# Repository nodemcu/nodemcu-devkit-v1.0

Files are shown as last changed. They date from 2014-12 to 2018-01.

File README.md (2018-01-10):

NodeMCU DEVKIT V1.0
==============

A development kit for NodeMCU firmware.

It will make NodeMCU more easy. With a micro USB cable, you can connect NodeMCU devkit to your laptop and flash it without any trouble, just like Arduino.

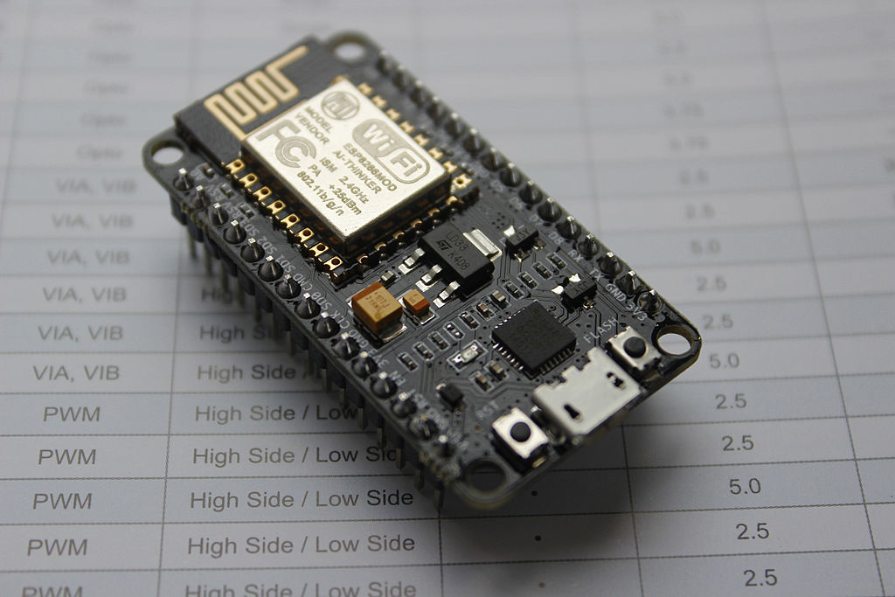
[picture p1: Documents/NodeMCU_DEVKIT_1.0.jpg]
DEVKIT


It is an open hardware, with ESP-12-E core [32Mbits(4MBytes) flash version].

## How to flash
- - - - - -
UPDATE
New nodemcu-flasher is released.
Bug fixed. please use latest software and re-flash.
Enjoy.
https://github.com/nodemcu/nodemcu-flasher
- - - - - -
If always have problem, please use latest flash download tool from espressif.
http://bbs.espressif.com/viewtopic.php?f=5&t=433
Please use DIO mode and 32M flash size option, and flash latest firmware to 0x00000.
Before flashing firmware, please hold FLASH button, and press RST button once.
When our firmware download tool released, it will flash firmware automatically and needn't press any button.

## Pin map

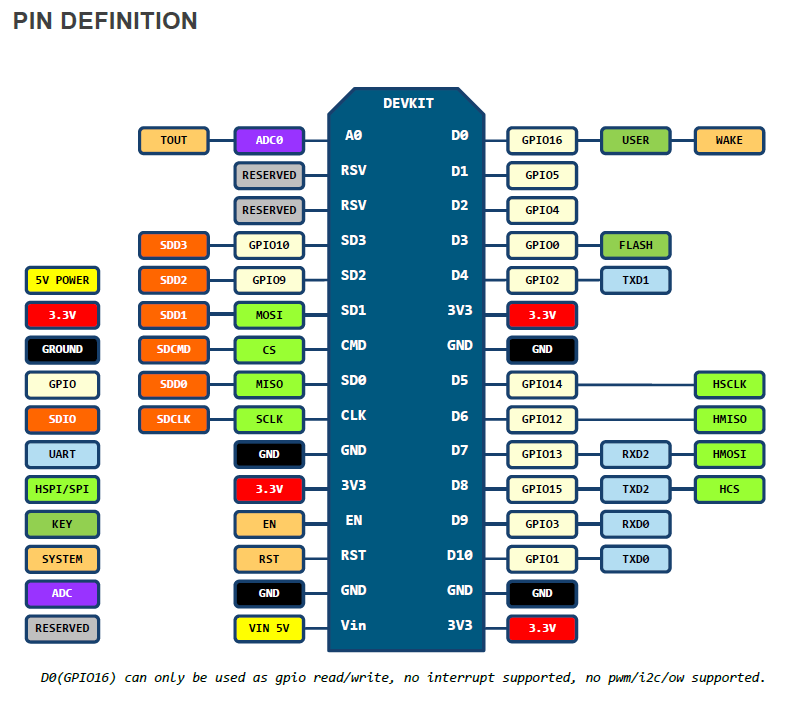
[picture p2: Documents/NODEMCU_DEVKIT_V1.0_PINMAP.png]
PIN MAP


It is designed by Altium Designer, and fully open–source. Now everyone can make their own NODEMCU.

## Designator & Parameter

|Designator|Parameter|
|-|-|
|C1,C4,C6 |100nF (104) ±10% 16V|
|C2 |100uF(107) ±10% 6.3V Case B 3528|
|C3,C5,C8 |10uF(106) ±20% 10V |
|C7|10uF(106) ±10% 25V|
|D1|SOD-123 40V,1A,VF=0.45V@1A|
|LED1|1.6x0.8x0.6 Iv= 35~65mcd @IF=5mA ESD:1000V |
|R1,R2,R3,R4,R5,R7,R8|12KΩ (1202) ±1% 0.0625W [50V TYP] [100V MAX] T.C.R ±100|
|R6,R9,R11,R12|470Ω (4700) ±1% 0.0625W [50V TYP] [100V MAX] T.C.R ±100|
|R10(Do not install)|0Ω (0R00) ±1% 0.0625W [50V TYP] [100V MAX] T.C.R ±100|
|R13|220kΩ (2203) ±1% 0.0625W [50V TYP] [100V MAX] T.C.R ±100|
|R14|100kΩ (1003) ±1% 0.0625W [50V TYP] [100V MAX] T.C.R ±100|

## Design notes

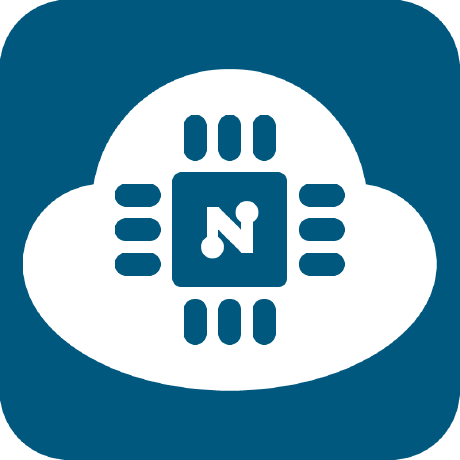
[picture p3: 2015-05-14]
Documents/NodeMCU.png

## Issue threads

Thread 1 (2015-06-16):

File writes fail all the time

rjpcomputing, 2015-06-16:
Hi,

I can not save files to the file system on my board. I have tried the last 4 firmware releases and it doesn't change the problem. It seems to be related to the  amica boards. I have the revision before this and it works 100% of the time.

```lua
file.open("script1.lua","w+")
file.writeline([[print( "Hello World" )]])
file.close()
```
**OUTPUT**:
```
stdin:1: open a file first
```

I am opening the file on the first line.

Please help

vowstar, 2015-06-17:
Hello, you may use old flashtool.
Options:
1. Please use latest esptool.py and with DIO option to flash firmware.
https://github.com/themadinventor/esptool
2. Please use latest NodeMCU flasher with default option (must click 'restore to default' in advanced tab)
https://github.com/nodemcu/nodemcu-flasher
3. Please use latest Espressif's flash tool(without auto download support)
If always have problem, please use latest flash download tool from espressif. http://bbs.espressif.com/viewtopic.php?f=5&t=433 Please use DIO mode and 32M flash size option, and flash latest firmware to 0x00000. Before flashing firmware, please hold FLASH button, and press RST button once. When our firmware download tool released, it will flash firmware automatically and needn't press any button.

rjpcomputing, 2015-06-17:
Hi,

I have been using `esptool.py` downloaded from the master branch (e96336f6561109e67afe03c0695d1e5b0de15da6) and it did not work.

Here is the commandline I am using:
```
./esptool.py --port /dev/ttyUSB0 write_flash 0x00000 <firmware> -fs 32m -fm dio -ff 40m
```
I am using the Amica black board on Linux.

Air000, 2015-06-26:
I have the same problem with @rjpcomputing , also using the Amica black board.
I tried all the methods. Only the tool on http://bbs.espressif.com/viewtopic.php?f=5&t=433 work fine.
But I need esptool.py on Linux

leonciokof, 2015-07-13:
@Air000 how to use esptool from http://bbs.espressif.com/viewtopic.php?f=5&t=433 ?

Air000, 2015-07-17:
@leonciokof
my esptool.py is download from https://github.com/themadinventor/esptool/blob/master/esptool.py.
and I test the esptool from  http://bbs.espressif.com/viewtopic.php?f=5&t=433, also output nothing.

rjpcomputing, 2015-07-23:
@vowstar Why is this closed? The bug is not fixed. Should this be reported on a different tracker?

I don't think that Wine + flash_download_tool.exe is a good enough solution when a feature of NodeMCU is cross-platform.

Thoughts?

rjpcomputing, 2015-07-23:
I think esptool might have got a fix. I have yet to test it, but the commit looks like it should work.
https://github.com/themadinventor/esptool/commit/043f9287c6f7d8a8c2579395f790629f3d85683c

Has anyone tried esptool after July 8th?

rjpcomputing, 2015-08-03:
Just to let other know I was able to use the latest esptool (>July 8th) to flash the board.

Closed 2015-07-23.

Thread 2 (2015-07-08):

CP2102 OSX drivers?

MacDada, 2015-07-08:
Where do I find **working** drivers for OSX 10.10 (Yosemite)?

1. I have OSX `10.10.3` on `MBP11,2`
2. I downloaded OSX drivers from [the vendor website](https://www.silabs.com/products/mcu/Pages/USBtoUARTBridgeVCPDrivers.aspx) ([direct zip download](https://www.silabs.com/Support%20Documents/Software/Mac_OSX_VCP_Driver.zip))
3. Unpacked the ZIP, mounted DMG file, installed using the PKG installer.
4. Restarted computer
5. I connected NodeMcu devkit v1.0 through USB 3.0 port

There is a file/folder `/Library/Extensions/SiLabsUSBDriver.kext`, but no serial port available for the device.

```
$ ls -lah /dev/cu*
crw-rw-rw-  1 root  wheel   18,   1 Jul  8 13:32 /dev/cu.Bluetooth-Incoming-Port
crw-rw-rw-  1 root  wheel   18,   3 Jul  8 13:32 /dev/cu.Bluetooth-Modem
crw-rw-rw-  1 root  wheel   18,   5 Jul  8 13:32 /dev/cu.DadaFon4-WirelessiAP

$ ls -lah /dev/tty.*
crw-rw-rw-  1 root  wheel   18,   0 Jul  8 13:32 /dev/tty.Bluetooth-Incoming-Port
crw-rw-rw-  1 root  wheel   18,   2 Jul  8 13:32 /dev/tty.Bluetooth-Modem
crw-rw-rw-  1 root  wheel   18,   4 Jul  8 13:32 /dev/tty.DadaFon4-WirelessiAP
```

No success with ESPlorer and Arduino IDE.

----
__EDIT 1__

Apparently it works for some people (?), but not for me: http://blog.squix.ch/2015/05/esp8266-flashing-nodemcu-v10-on-mac-os.html

----
__EDIT 2:__

It looks like the kext isn't loaded?

```
$ kextstat
Index Refs Address            Size       Wired      Name (Version) <Linked Against>
    1   92 0xffffff7f80a3e000 0x8c50     0x8c50     com.apple.kpi.bsd (14.3.0)
    2    7 0xffffff7f80f9c000 0x28c0     0x28c0     com.apple.kpi.dsep (14.3.0)
    3  118 0xffffff7f80a03000 0x20500    0x20500    com.apple.kpi.iokit (14.3.0)
    4  125 0xffffff7f80a24000 0xbf50     0xbf50     com.apple.kpi.libkern (14.3.0)
    5  108 0xffffff7f80a00000 0x2d50     0x2d50     com.apple.kpi.mach (14.3.0)
    6   53 0xffffff7f80a30000 0x8590     0x8590     com.apple.kpi.private (14.3.0)
    7   71 0xffffff7f80a39000 0x4900     0x4900     com.apple.kpi.unsupported (14.3.0)
    8    4 0xffffff7f80da3000 0x9c000    0x9c000    com.apple.kec.corecrypto (1.0) <7 6 5 4 3 1>
    9    0 0xffffff7f80ea4000 0xc000     0xc000     com.apple.kec.pthread (1) <7 6 5 4 1>
   10    1 0xffffff7f80fd5000 0x9000     0x9000     com.apple.kec.Libm (1) <4>
   11   23 0xffffff7f813b7000 0x9000     0x9000     com.apple.iokit.IOACPIFamily (1.4) <7 6 4 3>
   12   31 0xffffff7f80b24000 0x2f000    0x2f000    com.apple.iokit.IOPCIFamily (2.9) <7 6 5 4 3>
   13    2 0xffffff7f82956000 0x5f000    0x5f000    com.apple.driver.AppleACPIPlatform (3.1) <12 11 7 6 5 4 3 1>
   14    1 0xffffff7f810a5000 0xb000     0xb000     com.apple.driver.AppleFDEKeyStore (28.30) <8 7 6 5 4 3 1>
   15    2 0xffffff7f813b0000 0x7000     0x7000     com.apple.iokit.IOReportFamily (31) <5 4 3>
   16   10 0xffffff7f80a47000 0x26000    0x26000    com.apple.iokit.IOStorageFamily (2.0) <7 6 5 4 3 1>
   17    0 0xffffff7f814a7000 0x19000    0x19000    com.apple.driver.DiskImages (396) <16 7 6 5 4 3 1>
   18    1 0xffffff7f822ce000 0xf000     0xf000     com.apple.driver.AppleCredentialManager (1.0) <7 5 4 3 1>
   19    2 0xffffff7f80fa2000 0xd000     0xd000     com.apple.driver.AppleMobileFileIntegrity (1.0.5) <7 6 5 4 3 2 1>
   20    0 0xffffff7f822dd000 0x23000    0x23000    com.apple.driver.AppleKeyStore (2) <19 18 8 7 6 5 4 3 1>
   21    0 0xffffff7f80f9f000 0x2000     0x2000     com.apple.security.TMSafetyNet (8) <7 6 5 4 2 1>
   22    2 0xffffff7f80faf000 0x5000     0x5000     com.apple.kext.AppleMatch (1.0.0d1) <4 1>
   23    1 0xffffff7f80fb4000 0x17000    0x17000    com.apple.security.sandbox (300.0) <22 19 7 6 5 4 3 2 1>
   24    0 0xffffff7f80fcb000 0x9000     0x9000     com.apple.security.quarantine (3) <23 22 7 6 5 4 2 1>
   25    0 0xffffff7f829cc000 0x8000     0x8000     com.apple.nke.applicationfirewall (161) <7 6 5 4 3 1>
   26    0 0xffffff7f82929000 0x3000     0x3000     com.apple.driver.AppleAPIC (1.7) <4 3>
   27    3 0xffffff7f81358000 0x4000     0x4000     com.apple.iokit.IOSMBusFamily (1.1) <5 4 3>
   28    0 0xffffff7f829bb000 0x7000     0x7000     com.apple.driver.AppleACPIEC (3.1) <27 13 11 5 4 3>
   29    0 0xffffff7f821e9000 0x4000     0x4000     com.apple.driver.AppleSMBIOS (2.1) <7 4 3>
   30    0 0xffffff7f82546000 0x3000     0x3000     com.apple.driver.AppleHPET (1.8) <11 7 5 4 3>
   31    6 0xffffff7f810b0000 0x76000    0x76000    com.apple.iokit.IOHIDFamily (2.0.0) <14 7 6 5 4 3 2 1>
   32    0 0xffffff7f829c5000 0x4000     0x4000     com.apple.driver.AppleACPIButtons (3.1) <31 13 11 7 6 5 4 3 1>
   33    0 0xffffff7f8220a000 0x8000     0x8000     com.apple.driver.AppleRTC (2.0) <11 5 4 3 1>
   34    1 0xffffff7f825bb000 0x5000     0x5000     com.apple.driver.AppleEFIRuntime (2.0) <7 6 5 4 3>
   35    0 0xffffff7f821d1000 0x8000     0x8000     com.apple.driver.AppleSmartBatteryManager (161.0.0) <27 11 5 4 3 1>
   36    1 0xffffff7f825c0000 0xb000     0xb000     com.apple.driver.AppleEFINVRAM (2.0) <34 7 6 5 4 3 1>
   37   16 0xffffff7f8101d000 0x65000    0x65000    com.apple.iokit.IOUSBFamily (720.4.4) <12 7 5 4 3 1>
   38    0 0xffffff7f81158000 0x22000    0x22000    com.apple.driver.AppleUSBXHCI (710.4.11) <37 12 7 5 4 3 1>
   39    5 0xffffff7f80fde000 0x2c000    0x2c000    com.apple.iokit.IONetworkingFamily (3.2) <7 6 5 4 3 1>
   40    1 0xffffff7f816de000 0x7000     0x7000     com.apple.driver.mDNSOffloadUserClient (1.0.1b8) <39 4 3 1>
   41    1 0xffffff7f816e5000 0xab000    0xab000    com.apple.iokit.IO80211Family (730.60) <39 8 7 6 5 4 3 1>
   42    0 0xffffff7f81798000 0x5e6000   0x5e6000   com.apple.driver.AirPort.Brcm4360 (930.37.3) <41 40 39 12 7 6 5 4 3 1>
   43    7 0xffffff7f8123f000 0xde000    0xde000    com.apple.iokit.IOThunderboltFamily (4.2.2) <5 4 3 1>
   44    0 0xffffff7f820f1000 0x1b000    0x1b000    com.apple.driver.AppleThunderboltNHI (3.1.7) <43 12 11 5 4 3 1>
   45    0 0xffffff7f820df000 0x5000     0x5000     com.apple.driver.AppleThunderboltPCIDownAdapter (2.0.2) <43 12 5 4 3 1>
   46    3 0xffffff7f82133000 0xf000     0xf000     com.apple.driver.AppleThunderboltDPAdapterFamily (4.0.6) <43 11 5 4 3 1>
   47    0 0xffffff7f8215d000 0x6000     0x6000     com.apple.driver.AppleThunderboltDPInAdapter (4.0.6) <46 43 5 4 3 1>
   48    3 0xffffff7f81686000 0x16000    0x16000    com.apple.iokit.IOAHCIFamily (2.7.5) <5 4 3 1>
   49    0 0xffffff7f8292e000 0x1b000    0x1b000    com.apple.driver.AppleAHCIPort (3.1.2) <48 12 5 4 3 1>
   50    0 0xffffff7f816ac000 0x9000     0x9000     com.apple.iokit.IOAHCIPassThrough (1.0.3) <48 5 4 3 1>
   51    0 0xffffff7f816b9000 0x18000    0x18000    com.apple.iokit.IOAHCIBlockStorage (2.7.1) <48 16 6 5 4 3 1>
   52    0 0xffffff7f81fb9000 0x3000     0x3000     com.apple.driver.XsanFilter (404) <16 5 4 3 1>
   53    0 0xffffff7f811bd000 0x1c000    0x1c000    com.apple.driver.AppleUSBHub (705.4.2) <37 5 4 3 1>
   54    0 0xffffff7f81ef5000 0xa000     0xa000     com.apple.BootCache (36) <7 6 5 4 3 1>
   55    0 0xffffff7f8284c000 0x2000     0x2000     com.apple.driver.AppleFileSystemDriver (3.0.1) <16 4 3>
   56    0 0xffffff7f82850000 0x5000     0x5000     com.apple.AppleFSCompression.AppleFSCompressionTypeZlib (1.0.0d1) <6 4 3 2 1>
   57    0 0xffffff7f82857000 0x3000     0x3000     com.apple.AppleFSCompression.AppleFSCompressionTypeDataless (1.0.0d1) <7 6 4 3 2 1>
   58    1 0xffffff7f81df7000 0xde000    0xde000    com.apple.driver.CoreStorage (471.20.7) <16 7 6 5 4 3 1>
   59    0 0xffffff7f81edb000 0x16000    0x16000    com.apple.driver.CoreStorageFsck (471.20.7) <58 16 7 6 5 4 3 1>
   60    1 0xffffff7f8114e000 0xa000     0xa000     com.apple.driver.AppleUSBComposite (705.4.9) <37 4 3 1>
   61    0 0xffffff7f811b6000 0x7000     0x7000     com.apple.driver.AppleUSBMergeNub (705.4.0) <60 37 4 3 1>
   62    4 0xffffff7f80ae2000 0x2b000    0x2b000    com.apple.iokit.IOSCSIArchitectureModelFamily (3.7.5) <5 4 3 1>
   63    1 0xffffff7f8108e000 0x11000    0x11000    com.apple.iokit.IOUSBMassStorageClass (3.7.2) <62 37 16 5 4 3 1>
   64    1 0xffffff7f80eb0000 0x18000    0x18000    com.apple.iokit.IOSCSIBlockCommandsDevice (3.7.5) <62 16 5 4 3 1>
   65    0 0xffffff7f821b6000 0x8000     0x8000     com.apple.driver.AppleUSBCardReader (3.5.5) <64 63 62 37 16 5 4 3 1>
   66    0 0xffffff7f8135c000 0x7000     0x7000     com.apple.iokit.SCSITaskUserClient (3.7.5) <62 16 5 4 3 1>
   67    3 0xffffff7f81144000 0xa000     0xa000     com.apple.iokit.IOUSBHIDDriver (705.4.0) <37 31 5 4 3 1>
   68    0 0xffffff7f81ff2000 0x4000     0x4000     com.apple.driver.AppleUSBTCKeyboard (240.2) <67 37 31 7 6 5 4 3 1>
   69    0 0xffffff7f81ff8000 0x2000     0x2000     com.apple.driver.AppleUSBTCKeyEventDriver (240.2) <31 5 4 3>
   70    0 0xffffff7f82001000 0x13000    0x13000    com.apple.driver.AppleUSBMultitouch (245.2) <67 37 31 6 5 4 3 1>
   71    0 0xffffff7f81ffc000 0x3000     0x3000     com.apple.driver.AppleUSBTCButtons (240.2) <67 37 31 7 6 5 4 3 1>
   72   16 0xffffff7f81450000 0x3b000    0x3b000    com.apple.iokit.IOGraphicsFamily (2.4.1) <12 7 5 4 3 1>
   73    1 0xffffff7f8227b000 0xe000     0xe000     com.apple.driver.AppleSMBusController (1.0.13d1) <27 12 11 5 4 3>
   74    0 0xffffff7f8228c000 0xe000     0xe000     com.apple.driver.AppleMCCSControl (1.2.11) <73 72 12 11 7 5 4 3 1>
   75    4 0xffffff7f81497000 0x10000    0x10000    com.apple.iokit.IONDRVSupport (2.4.1) <72 12 7 5 4 3>
   76    6 0xffffff7f813ca000 0x1a000    0x1a000    com.apple.driver.AppleSMC (3.1.9) <11 7 5 4 3 1>
   77    2 0xffffff7f82820000 0x5000     0x5000     com.apple.driver.AppleBacklightExpert (1.1.0) <75 72 12 5 4 3>
   78    0 0xffffff7f82921000 0x5000     0x5000     com.apple.driver.AppleBacklight (170.7.4) <77 76 75 72 12 5 4 3>
   79    2 0xffffff7f8281d000 0x3000     0x3000     com.apple.driver.AppleGraphicsControl (3.10.22) <72 12 11 7 5 4 3 1>
   80    0 0xffffff7f82825000 0x14000    0x14000    com.apple.driver.AppleMuxControl (3.10.22) <79 77 72 12 11 7 6 5 4 3 1>
   81    1 0xffffff7f82142000 0xe000     0xe000     com.apple.driver.AppleThunderboltDPOutAdapter (4.0.6) <46 43 5 4 3 1>
   82    0 0xffffff7f82150000 0xd000     0xd000     com.apple.driver.AppleThunderboltEDMSink (4.0.2) <81 46 43 5 4 3 1>
   83    6 0xffffff7f813c0000 0xa000     0xa000     com.apple.driver.IOPlatformPluginFamily (5.9.1d7) <11 7 6 5 4 3>
   84    1 0xffffff7f813e6000 0x17000    0x17000    com.apple.driver.X86PlatformPlugin (1.0.0) <83 76 37 11 7 6 5 4 3 1>
   85    1 0xffffff7f81406000 0x12000    0x12000    com.apple.driver.IOPlatformPluginLegacy (1.0.0) <83 11 7 6 5 4 3>
   86    0 0xffffff7f8141a000 0x10000    0x10000    com.apple.driver.ACPI_SMC_PlatformPlugin (1.0.0) <85 83 76 12 11 7 6 5 4 3>
   87    1 0xffffff7f8134e000 0x5000     0x5000     com.apple.iokit.IOSlowAdaptiveClockingFamily (1.0.0) <7 6 5 4 3 1>
   88    0 0xffffff7f82300000 0x2000     0x2000     com.apple.driver.AppleIntelSlowAdaptiveClocking (4.0.0) <87 4 3>
   89    2 0xffffff7f8234f000 0x6f000    0x6f000    com.apple.iokit.IOAcceleratorFamily2 (156.14) <72 12 7 6 5 4 3 1>
   90    3 0xffffff7f82456000 0x6000     0x6000     com.apple.AppleGraphicsDeviceControl (3.10.22) <7 6 5 4 3 1>
   91    0 0xffffff7f8245c000 0x4b000    0x4b000    com.apple.driver.AppleIntelFramebufferAzul (10.0.6) <90 89 72 15 12 11 7 6 5 4 3 1>
   92    0 0xffffff7f82860000 0xa8000    0xa8000    com.apple.driver.AppleCameraInterface (5.33.0) <12 7 6 5 4 3 1>
   93    0 0xffffff7f821de000 0x5000     0x5000     com.apple.driver.AppleSMCLMU (2.0.7d0) <76 72 5 4 3>
   94    1 0xffffff7f810a2000 0x3000     0x3000     com.apple.iokit.IOUSBUserClient (705.4.0) <37 7 5 4 3 1>
   95    0 0xffffff7f821e6000 0x3000     0x3000     com.apple.driver.AppleSMBusPCI (1.0.12d1) <12 5 4 3>
   96    2 0xffffff7f81f01000 0x78000    0x78000    com.apple.vecLib.kext (1.2.0) <10 6 5 4 3>
   97    4 0xffffff7f81f79000 0x30000    0x30000    com.apple.iokit.IOAudioFamily (203.3) <96 5 4 3 1>
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

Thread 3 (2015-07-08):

Cannot flash the firmware from a Mac

marcoskirsch, 2015-07-08:
I have OS X Yosemite. SiLabs drivers for the USB-Serial adapter are installed and working. I can communicate to the board via /dev/cu.SLAB_USBtoUART and I can use it in screen, ESPlorer, esptool.py... but strangely not minicom.

However, I haven't been able to flash new firmware successfully.

Can anyone confirm this can be done? I did it on older ESP01 hardware before but I don't rule out me doing something stupid.

* What tool did you use to flash?
* What firmware image?

I posted additional information here: http://www.esp8266.com/viewtopic.php?f=22&t=3903 but nobody has been able to help. Help is appreciated!

abl, 2015-07-08:
Minicom requires some tweaks to work correctly, iirc - it has to be told to ignore certain signals and lines that are being repurposed.

Ok, so you are actually flashing the build and getting to boot mode 3, which is boot from SPI flash. (Esptool, with a supported USB->Serial, is able to reset devices and put them in to boot mode 1, which is what you use for writing to the flash.) Secondary boot mode not being 7 I tend to associate with power supply issues. I've never found a concrete answer as to what it means.

Based on other bug reports, it looks like you might have a defective flash chip or a nonstandard flash chip - or you're flashing bad firmware. Have you tried flashing the stock NodeMCU firmware? Do you have access to a Windows machine to try the official NodeMCU flasher?

marcoskirsch, 2015-07-08:
I doubt but don't completely rule out a defective flash chip because it was functional out of the box. I do have access to Windows PC and will try that next. In order to rule out a bad firmware image, can you link to an image that is known to work on NodeMCU devkit 1.0?

abl, 2015-07-08:
http://www.esp8266.com/viewtopic.php?p=15306 kind of indicates that, based on your error, something weird is going on with your flash chip. It might need a specialized flasher or a different header. This wouldn't have been a problem...until you tried to flash it or write a large amount of data to flash.

The NodeMCU flasher comes with NodeMCU firmware. I'm not sure which version, though.

Official NodeMCU releases are at https://github.com/nodemcu/nodemcu-firmware/releases - I don't have a NodeMCU 1.0 to test on but I'd expect a lot of issues filed if any of these builds were broken.

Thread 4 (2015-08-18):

V1/V2/V3 difference ?

asetyde, 2015-08-18:
Schematics say about v 0,9 .. but many type at now .. v1 v2 v3 ... therefore ? thx

mqu, 2015-10-25:
you could have a look here : http://frightanic.com/iot/comparison-of-esp8266-nodemcu-development-boards/

asetyde, 2015-10-25:
Many Thx ,

I also understand with my hand this difference , it's a good choice model v2 also doit v3.

In particular about power , use reserve pin to give a special port is more safe and practical that use vin/gnd as bridge to give power.

Minimum power is about 500ma , after 6 month of use I say 1000ma is good .
With sensor and rele 1.5k ma or 2k ma because this board is sensible to lower power down , strange error may appear if power is not enough to cpu minimum needed .

But this board , I think , is a big big successful ! This community also too.

Sent from my iPhone

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

vowstar, 2015-11-24:
NodeMCU only released V0.9 and V1.0 board. The next is V1.1, we plan to release it in 2016.
The main difference is USB to UART bridge IC. V0.9 uses ch340G, but have many problems on MAC, so we released V1.0 which uses CP2102 and have a good performance.

odoveiz, 2016-03-25:
Any news on a new version?

asetyde, 2016-03-29:
on closed issue you can find info , use search

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

asetyde, 2016-03-29:
https://github.com/esp8266/Arduino/issues/1481

asetyde, 2016-03-29:
only nodemcu v2 as nodemcu 1.0 is amica / nodemcu compliance
( v3 has usb different chip ch340 and some power difference / v1 is nodemcu 0.9 )

i suggest use nodemcu 1.0 amica ( v2 ) see post how check it

jk2552, 2017-10-05:
hi folks i need Datasheet of Nodemcu ver0.1 kindly anyone help me..

marcelstoer, 2017-12-27:
Sorry to comment on an old and closed issue. My post that was mentioned above has a photo at https://frightanic.com/iot/comparison-of-esp8266-nodemcu-development-boards/#official-vs-unofficial which shows in detail how an "official" 1.0/v2 devkit has to look like.

To my knowledge neither Banggood nor Aliexpress still sells the Amica v2 devkit. Seeed Studio still has them but it's marked as "out of stock". If you [search taobao.com for "NodeMCU cp2102"](https://s.taobao.com/search?q=NodeMCU+cp2102) it turns up quite a few that look genuine.

Closed 2016-03-29.

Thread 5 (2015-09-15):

Unable to connect to dev kit at all

zdrc, 2015-09-15:
Hi, I recently purchased a nodeMCU dev kit off of amazon.

I'm running Mac 10.10, and I have the most recent CP2102 driver. I own a couple of CP2102 breakouts that I can connect to no problem.

I am entirely unable to get any kind of response out of the dev kit using the micro USB port. Nothing shows up under /dev/tty.* and IO Registry Explorer is unable to locate the device in the USB port. I've tried to circumvent the CP2102 chip on the dev kit using one of my breakouts (connecting txd and rxd) and I seem to be able to connect to the module. I was having trouble communicating with the firmware (it was acting a little erratic) so I decided to reflash the AT firmware then the nodeMCU firmware. After reflashing I am unable to get any kind of response out of the chip over serial (through either AT or nodeMCU).

Is there anything I can do or is the module simply defective?

vowstar, 2015-11-24:
Please check
/Library/Extensions/SiLabsUSBDriver.kext
$ ls -lah /dev/cu*
may be it is not /dev/tty*

zdrc, 2015-11-24:
I have the driver. That directory checks out. It's not in /dev/cu*.

This is old, but I now believe me problem was I set the flash setting improperly. Unfortunately, I don't have access to the dev kit anymore.

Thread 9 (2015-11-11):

Vin 5V not working

confile, 2015-11-11:
I the pin image you labeled VIN 5V. This does not work by default. Is there a way to activate it?

vowstar, 2015-11-24:
Between Vin 5V and VDDUSB is a diode, 1n5817, Please connect USB cable and test the Vin voltage, and test LM1117's Vout. And then disconnect USB cable, supply Vin 5V to 9V, redo the test. If no voltage, please check the wire between Vin and LM1117

confile, 2015-11-25:
I connected the dev kit to USB. In this case Vin 5V has no power. What is Win 5V used for. Is it used for an external power supply instead of USB? Does it mean you can plug the dev board to a 5V power supply instead of USB? Is Vin 5V only input power but not output power, i.e., when you use USB to power the dev board there is no outgoing power of 5V on Vin 5v?

PaulHam211, 2016-01-24:
Is VIN only for input power? I have a pref connected to VIN and its not powering.
Shame because i need to have a external 5v PSU while prototyping, I should be able to tap 5v from the USB.

asetyde, 2016-01-25:
also output 5v power
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

christianbur, 2016-02-14:
is it possible to connect a 5v sensor to vin 5v (the power supply is usb)?

asetyde, 2016-02-15:
Yes , i use it

remedix, 2016-02-28:
@vowstar so vin takes 5V to 9V ? So if I connect a 9V battery to 'VIN' pin and any 'G' pin that would power it up right ?

MrAda, 2016-08-12:
I have tried to plug USB cable into board and then did a reading on all of the power pins.  The three 3.3V and the one 5.0V.  Only the 3.3V seem to be providing power.  The 5.0V has really low voltage, not 0 but really low.  @asetyde stated he uses it.  Maybe he can tell us what we have to do to make it happen?  I want to be able to power the board with a 5V source.

shadowhorst, 2016-08-13:
I had the same issue with my VIN pin not providing any voltage. But in my case there is also an VU pin on the board which gives me 5V output voltage.

MrAda, 2016-08-13:
I got lucky and mine works.  You can't plug the USB cable in while powering trying to power with the 5V pin.  I have to see where this VU pin is.  I just checked my PNG against my board and the PNG is wrong!  It doesn't show VU pin.  Do you have a good picture I can see that describes the pins?  This is great news to me as I was trying to power a relay and couldn't with the 3.3V output.

MrAda, 2016-08-13:
Grrrrrrr.  My VU pin is showing less than 1V.  I really need to use this for my relay.

MrAda, 2016-08-13:
You have to have usb plugged in

drawkula, 2016-08-13:
[This NodeMCU boards comparison](http://frightanic.com/iot/comparison-of-esp8266-nodemcu-development-boards/) shows the pinouts of the commin NodeMCU siblings.

VU (USB power) is an invention of the ptoducer "LoLin" and the other siblings don't have it.

MrAda, 2016-08-13:
I am so happy that I picked the right sibling!  My Version 3 LoLin has this and now I can control my relays.

shadowhorst, 2016-08-14:
@drawkula Thanks for the great link. Have been looking for exactly something like that when I was choosing a NodeMCU board.

supersjimmie, 2016-08-31:
My NodeMCU board does have this VIN pin (not the VU).
When I only power this VIN with 5V, the board does not boot. (short blink of blue led, then nothing)
When I also connect USB to my laptop it boots fine and keeps running on the VIN 5V when I then disconnect USB.

Tried it with 3 different 5V sources, an unknown 5V/1A adapter and 2 Apple adapters (1A and 2A versions). I did this with a stripped USB cable to extract the 5V directly from the adapter and inject it into the VIN 5V pin.
(so to be clear, I don't connect the adapter to the USB but to the VIN)

I don't understand why the board only needs USB power to boot and then runs fine without it.

MrAda, 2016-08-31:
Do you know which version of the board you have?  Sounds like you don't have the latest.  The VU pin, third down on the left side (next to ESP chip) has  a 5V out pin called VU (or VV maybe my eyes can't see it).  I have tried to power this unit with wires instead of the usb and I don't remember if I was successful, or I just couldn't tell.  Need the usb to download to it.  If you downloaded a lua file that just blinked the led then you could tell if the power sources work or not as a running app.  Eventually I'll have to pull power off of a brick or buck converter so once I get some new ones in, I'll report how well it goes.

supersjimmie, 2016-09-02:
My NodeMCU is v2. I have now discovered that, probable because there is a protecting diode that lowers the voltage just a bit, my module does boot but fails to connect wifi. As soon as I power with usb, the voltage gets just a bit higher and wifi connects.  I will try to solve this by searching a power supply with a bit more than 5V.

oshamed, 2016-09-24:
It works for me using 7.5 volt adapter to 5 volt regulator then to my esp

Imara90, 2016-10-12:
@supersjimmie did you end up solving this? I have the same problem

tablatronix, 2017-03-23:
I use VIN works fine, maybe you have voltage drop on your 5v, probably need 5.2v

StalePhish, 2018-03-11:
I have the ESP12E DEVKIT V2 board with NodeMCU (from HackerBox) and I'm experiencing the same problem.

If I plug in USB, it boots and I get 4.65V off the VIN.
If I plug in a 9V battery to VIN and GND, it does NOT boot, and I get around 8.5V off the VIN. It's like when you plug in USB, it's doing something different.

rsagittario59, 2018-03-19:
My NodeMCU board does have this VIN pin (not the VU).
When I only power this VIN with 5V, the board does not boot. (short blink of blue led, then nothing)
When I also connect USB to my laptop it boots fine and keeps running on the VIN 5V when I then disconnect USB.

Tried it with 3 different 5V sources, an unknown 5V/1A adapter and 2 Apple adapters (1A and 2A versions). I did this with a stripped USB cable to extract the 5V directly from the adapter and inject it into the VIN 5V pin.
(so to be clear, I don't connect the adapter to the USB but to the VIN)

I don't understand why the board only needs USB power to boot and then runs fine without it.

supersjimmie
StalePhish
Imara90
did you solve this problem? if yes .... How??
many thanks

bartieman, 2018-03-24:
I discovered that for my Lolin NodeMcu v3, the VU pin is only outputting 5V (approximately) if I power the board by USB. If I power the board with 5V using VIN and G, the VU pin is only outputting around 1.1V.

tablatronix, 2018-03-24:
It never occured to me that you guys are not using actual nodemcu boards, are you all using lolin r some other knockoffs ? I have amica nodemcu v2 boards and do not have an issue.

MrAda, 2018-03-24:
I have been watching these messages.  I have successful using my Lolin board but I basically had to feed a power brick to my USB cable which plugs into the usb port on the board.  This provides power to board and the other pin didn't seem to work out well.

rsagittario59, 2018-03-26:
Many Thanks for your answer

Inviato da Posta per Windows 10

Da: Chris Sparks
Inviato: sabato 24 marzo 2018 19:29
A: nodemcu/nodemcu-devkit-v1.0
Cc: rsagittario59; Comment
Oggetto: Re: [nodemcu/nodemcu-devkit-v1.0] Vin 5V not working (#9)

I have been watching these messages. I have successful using my Lolin board but I basically had to feed a power brick to my USB cable which plugs into the usb port on the board. This provides power to board and the other pin didn't seem to work out well.
—
You are receiving this because you commented.
Reply to this email directly, view it on GitHub, or mute the thread.

rsagittario59, 2018-03-26:
Many Thanks for your answer

Inviato da Posta per Windows 10

Da: Shawn A
Inviato: sabato 24 marzo 2018 15:14
A: nodemcu/nodemcu-devkit-v1.0
Cc: rsagittario59; Comment
Oggetto: Re: [nodemcu/nodemcu-devkit-v1.0] Vin 5V not working (#9)

It never occured to me that you guys are not using actual nodemcu boards, are you all using lolin r some other knockoffs ? I have amica nodemcu v2 boards and do not have an issue.
—
You are receiving this because you commented.
Reply to this email directly, view it on GitHub, or mute the thread.

rsagittario59, 2018-03-26:
Many Thanks for your answer

Inviato da Posta per Windows 10

Da: bartieman
Inviato: sabato 24 marzo 2018 15:11
A: nodemcu/nodemcu-devkit-v1.0
Cc: rsagittario59; Comment
Oggetto: Re: [nodemcu/nodemcu-devkit-v1.0] Vin 5V not working (#9)

I discovered that for my Lolin NodeMcu v3, the VU pin is only outputting 5V (approximately) if I power the board by USB. If I power the board with 5V using VIN and G, the VU pin is only outputting around 1.1V.
—
You are receiving this because you commented.
Reply to this email directly, view it on GitHub, or mute the thread.

togius, 2018-04-13:
Use VV Nodemcu port for 5V output.
[https://frightanic.com/iot/comparison-of-esp8266-nodemcu-development-boards/](url)
Best answer drawkula. thanks.

661995, 2018-05-29:
hello guys ?
i have a nodeMCU esp12E ELU devlpmnt board.. i m connecting 4 6V relay to vin pin. when i plug in a USB to my computer 1st and second relay is working fine . but when third relay is on my nodeMCU board was short. means vin and gnd was shord inide automatically and board is died.. someone plz help me to fix it.. how i solve this? can i use 6v relay instead of 5V relay ? is any connection issue in my prototyping ? san we must use a optotoupler for protection of microcontroller ? somebody plz help me

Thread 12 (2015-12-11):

Suggestions about new NodeMCU devkit based on ESP32

nodemcu, 2015-12-11:
Hi, all
since esp32 is out for beta, the chip is much more capable than esp8266.
I'd like to know that what features we should added to our new devkit.
usb chip? flash size? pin-to-pin compatible with devkit v1.0?
Thanks in advance.

TerryE, 2015-12-11:
Some things that we do know about the esp32 (compared to the esp8266:

*    Espressif have opened a new support site: [esp32.com](http://esp32.com/), but which is accessible by registered users.
*    It runs a dual core LX108 (rather than the single core LX106 on the 8266)
*    It has a lot more RAM ?128Kb or 256Kb? rather than 48Kb
*    It has more pin-outs and a richer set of peripherals.

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
Very little further detail is approved by Espressif for discussion in the public domain, but the dual core / single memory space aspects mean that the simple non-OS SDK is unlikely to port well.  You need some form of centralised lock management and resource allocation as is provided by RTOS, and hence any new SDK will need to run under RTOS.

There is so much that we don't know and until we do it is difficult to make concrete plans.

*    Will there be a material pricing differential between the esp32 and the esp8266?
*    What will be its availability and when?
*    Can the core developers get NDA access to the device specs?
*    Will Espressif keep the two devices in manufacture or will they be soon phasing out the esp8266?

Clearly the esp32 is the future, but to me one key issue is how long we have to maintain parallel support, because our development strategy will depend on where this is months or more than a year.  Another is the availability of esp32 hardware.

asetyde, 2015-12-11:
Very interesting !!!

Sent from my iPhone

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

AdySan, 2015-12-22:
Would love to see a JST socket to connect a LiPo battery + support for USB charging. Basically something like the Adafruit Feather HUZZAH.

vowstar, 2015-12-25:
I think a bran-new board is needed, because ESP32 have much more GPIOs, DAC, touch, etc.
The new board must very small and  could carry it in the pocket, and have on-board USB to UART.
We have found a good and cheap DC-DC power IC, more small and stable for new esp32. So I suggest that use DC-DC in new dev-board. And many user like IPEX interface and external antenna, so I think add both PCB antenna and IPEX interface is better.
The GPIO layout will looks like devkit1.0(amica) as much as possible, but can not pin-to-pin.
@AdySan I think we can make a core board and a battery board which including charger and PMIC, and battery interface, using stacked design.

AdySan, 2015-12-25:
Yeah a separate board would do. One thing incenvenient about NodeMCU dev kit is that the deep sleep mode is rather pointless since the USB-serial IC drains way more current even when the ESP8266 is in deep sleep. It would be nice to have the capability to un-power the USB-serial chip with a jumper or a 0 Ohm resistor.

sathishvasimalai, 2016-02-25:
how to buy esp32 development kit

goldenbr0wn, 2016-05-30:
More analog input would be great ! Maybe using a multiplexer ?

pathob, 2016-09-04:
Please, do not use a different pin mapping again (if it is not too late already). This can be really confusing...

jeffeb3, 2016-10-31:
Dunno if anyone is still looking at this, or if it will matter, since you might be well on your way to designing this board since the 32's have been sort of available already, but here are some of my thoughts:
1) There is a lot more I/O, and it will be hard to tell what people want. Maybe you could have a sort of break away section with a ton of I/O, but you can cut it off if you really just want some of the new features with a similar footprint to the current nodemcu.
2) The main focus of a subset of pins would be PWM, ADC, SPI, I2C, UART. I think you should be easily be able to get 12 or so pins and cover those things pretty well. A larger board version, or a version with a breakaway section can have an emphasis on the other port types.
3) I never messed with the sleep stuff of the nodemcu0or1, but from what I read you need to connect GPIO16 to EN. Maybe just do that in a trace or through a 0 Ohm resistor, and save us the space by not giving us GPIO16 or EN.

It really seems like you kind of want something like a mini and a mega version. The mini for battery/sleep/small stuff and the mega for easy/everything/touch. Ideally, the differences would be small enough that you could always run the same code on each, so they would need the same flash and general setup, you just couldn't connect the stuff that needed extra IO to the mini version. Maybe you also couldn't run off of a battery for the mega version, or some kind of compromise like that.

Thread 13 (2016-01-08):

NodeMCU v1.0 ESP8266 LiPoly/LiIon Backpack Rev. A

sabas1080, 2016-01-08:
A group of friends and I made a backpack for 1.0v NodeMcu hope you like it, we welcome your comments

https://www.tindie.com/products/sabas1080/nodemcu-v10-esp8266-lipolyliion-backpack-rev-a/

Discount code: BBF6B2F

Thanks

asetyde, 2016-01-08:
Please correct Link with spots

> https://www.tindie.com/products/sabas1080/nodemcu-v10-esp8266-lipolyliion-backpack-rev-a/
>
it's very interesting but also indicate a battery to combine .. and capacity duration etc

Sent from my iPhone

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

Closed 2016-07-13.

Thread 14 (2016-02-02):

Impossible to flash/communicate

RataDP, 2016-02-02:
I'm having troubles to flash or connect my _devkit v1_. It arrived my home 2 days ago and I was not able to flash it or at least communicate with it.

I'm going to describe my case. I connect my _devkit v1_ via USB to microUSB with the CP2102 USBtoUARP, then the blue led of the ESP8266 blinks twice and stop. After this I can see the SSID "AI_THINKER_DA7E19" and connect to it, I got a 192.168.4.2 and the device .1. It answers to the ping but there is not webserver. Now I try to flash it, first I tried with Linux and ESPTool,

```
# python2 esptool.py --port /dev/ttyUSB0 write_flash 0x00000 firmware.bin
Connecting...

A fatal error occurred: Failed to connect to ESP8266
```

Well I read somewhere it could be a bug with ESPtool with high values of baudrate, so I tried with `--baud 9600` but the same output also with different baudrates. Meanwhile the program is in the state `connecting...`, the blue led blinks. I tried to reset with the Flash button pressed and the same result, nothing change. Also I tried wiring the GPIO0 to GND but still the same error.

Now it is the turn for Windows, I tried with the nodemcu-flasher, the driver was correctly install and the port is assigned correctly too. Select the COM port and set the baudrate to 9600 and flash. The log says `Begin to find ESP8266` enters in a loop and the blue led blinks every 1/2 seconds. Just to point it out, in the tab *operation* not appears any mac, it says "Waiting...". Just like before I changed the Baudrate and I tried all of them but nothing happens. _(I also press flash and reset like before but nothing)_

After all this troubles I tried to communicate with the devkit via Serial port with putty and Screen. The connection seems to be established but nothing appears in it. Pressing RST it should write something... garbage or some characters but nothing.

I don't know if I'm doing something wrong or the devkit it's broken. Some solution or tip?

Thank you

PD: I posted it in the old devkit repository, now it is in the correct repository.

EDIT:
@mrmonteith answered in the other repository.
```
I'm trying to remember when I first tried this. I think I used the flasher tool. You start the attempt at transfer, hold down the reset and flasher button, release the flasher button and then about a half second or so after release the reset. I don't have my device in front of me to check. Of course I only had to do it one time and I've had mine for about month. Hope it helps anyway.
```

I tried too, but no works it.

prob1995, 2016-10-04:
Same issue here... Still can't flash the firmware...

gurubhat, 2016-10-21:
change the USB cable.. had the same issue, resolved after changing the cable.

KOKONUTCREMEOG, 2017-05-29:
And here same issue. I operate PC Windows 10, And Android...,.But it's waiting for mac

ChrisHeerschap, 2017-06-22:
Found this page when dealing with the same problem. Swapped out USB cables to no avail. A little bit more searching and I found this which wound up fixing it for me - maybe it might be helpful to others:

http://kig.re/2014/12/31/how-to-use-arduino-nano-mini-pro-with-CH340G-on-mac-osx-yosemite.html

JayPalm, 2018-06-19:
Hey, did you ever figure this one out? I'm having pretty much the same issue on a Mac with a nodeMCU Amica board (uses a CP102 USB-UART bridge, installed the SiLab driver, etc). I have tried multiple baud rates but always get the same response: A fatal error occurred: Failed to connect to Espressif device: Timed out waiting for packet header.

I have tried multiple USB cables and multiple NodeMCUs to no avail. Really bummed right now...

ChrisHeerschap, 2018-06-19:
@JayPalm did you try the link I listed in [my last comment](https://github.com/nodemcu/nodemcu-devkit-v1.0/issues/14#issuecomment-310425447)?

Parin810, 2018-06-21:
Facing the same issue.. Anyone found the cause of the problem? or a solution that worked..

mrmonteith, 2018-06-29:
Any luck yet?  I had a couple of thoughts.  Mostly around possibly weak components.  Do you have any sort of oscilloscope? I bought a Hantek digital one that connects to the computer and does fairly good.  That would go a long ways to checking things like power supply voltages and noise on the lines.   But without you can still probably locate the issue.   A couple of things you can try.  That is put a capacitor between 3v3 and Gnd as an extra filter.  USB interfaces are notoriously noisy.    There is also an Espressif forum for issues with the ESP8266 and ESP32 devices.  You might post there too.

VinayKadalagi, 2018-11-25:
Just reconnect the usb cable keeping the flasher open
Look for log for below line ->
> Note:Detect serial port changed.
> Note:Auto MAP serial port.Port-->COM5
Then you should be able to flash. Looks like the tool cannot detect already connected device.

ersyncar, 2019-03-28:
i had same issue. i change usb cable and tried different values for advanced setting on Nodemcu. and it worked by
-Baudrate 9600, -flash size 4Mbyte, -flash speed 26.7mhz, -spi mode DIO

ThreeSpy712, 2019-03-29:
Try holding down the GPIO/reset button on your MCU, and then flash whilst still holding down. This worked for me.

Joshverge, 2019-03-30:
Same issue. Won't flash

Joshverge, 2019-03-30:
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

That's not the issue, it's able to detect the right com port right from the start

ersyncar, 2019-03-30:
>
> That's not the issue, it's able to detect the right com port right from the start

did you try by another usb cable. i had same issue and changed the cable. i tried by my printers cable and it worked :)

and i attached the picture of working settings on my ESP8266 -ESP 01

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

Joshverge, 2019-03-30:
Okay I resolved this for me. You just need to hold down the flash button until you the status bar moving forward after pressing flash

horodchukanton, 2020-08-10:
Mine was fixed by putting the board to an oven for two minutes. Looks like a weak components issue

Blazer9419, 2023-01-26:
I am also having the same issue. It says “waiting mac” however my FTDI and ESP is flashing red and the ESP was also flashing blue for a couple seconds then stopped. Is there anything I am doing wrong here?
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

TSRider85, 2023-11-25:
I had the same problem but i solved it, it was my usb port. Looks like it the current of that one was to low. So try a different usb port!

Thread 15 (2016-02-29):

Maximum Vin

adrianlzt, 2016-02-29:
I want to use the Vin pin to power NodeMCU, but it's not clear which is the maximum value we can use.

In the rear of the PCB it's written "Vin +5v recommended, +10V MAX".

But in this [pdf](https://github.com/nodemcu/nodemcu-devkit-v1.0/blob/master/NODEMCU_DEVKIT_V1.0.PDF), in the "POWER" section is written:
"Max Supply Voltage: 20V"

adrianlzt, 2016-02-29:
Looking at the [datasheet](https://github.com/nodemcu/nodemcu-devkit-v1.0/blob/master/Documents/NCP1117ST33T3G.PDF) of the power regulator

Vin should be between 4.75V and 10V

miguelpom, 2017-01-23:
Hi @adrianlzt.
I'm working on a project with the NodeMCU v1.0. Together with the Node I have an Arduino Nano running. Thus, to simplify my hardware design, I want to power the NodeMCU from a 5Volt external power source (the same that powers the Nano board).
Since you closed this issue, did you tried to power the NodeMCU from its Vin pin?
Were there any performance issues?
What's the version of the NodeMCU board you used?

Thank you in advance!

adrianlzt, 2017-01-23:
I was just exploring how can I power the NodeMCU, but haven't done it yet, sorry.

nedimhx, 2017-02-28:
Hello everyone,
@adrianlzt @miguelpom I'm working with NodeMCU for over 5 month, and it's time to test it on Maxell 9V alkaline battery. From 5 to 10 Vin is perfect solution.

downlz, 2017-09-14:
Thanks for the information.I was looking for the input voltage.The board pins more or less matches arduino Nano.

zfarrugia, 2017-12-03:
I can confirm that 15.5V will kill the board ... from experience.

mbfac, 2018-04-06:
Very bad experience with 12V.... works fine 1 minute.... :-(

Jmilesy, 2018-04-28:
However, after that 1 minute at 12v, you have a lovely bench heater, again from experience!!!

mmaxus35, 2018-08-14:
Thanks for the comments guys. I thought that i can handle up to 18V .. Yet, burned out at 16v :(

shakthi-arul, 2019-02-13:
This thread is useful. Thanks, guys!

fryguy04, 2019-02-26:
I had a NodeMCU in my attic working just fine for 6 months on 5V ... replaced it with 12V and ever since then it has been cyclic rebooting, it will work fine for a few minutes (maybe 5min) then reset itself. Converted back to 5V and back to working fine again ... Thanks to this Thread! I too thought i could use upwards of 12v, seems not to be true

gerritfries, 2019-07-12:
I have a NodeMCU Amica powered with 16V (the voltage of my doorbell) and it's working fine for two months now. I guess even though the voltage is a bit too high the ampere might be pretty low and thats the reason it works without problems.

joao-carvalheira, 2019-09-27:
> Hello everyone,
> @adrianlzt @miguelpom I'm working with NodeMCU for over 5 month, and it's time to test it on Maxell 9V alkaline battery. From 5 to 10 Vin is perfect solution.

Did it work?

Soraxem, 2020-07-07:
Mine turned to a heater at 8Volt?

L4RGER, 2020-10-28:
Im having trouble with a 5v power supply in at Vin. With power applied to board doesn’t work until reset button is pushed and then it works fine until next power cycle. Then it requires a reset again.
Going to rewire and supply 9v to Vin

ROBBED666, 2020-12-09:
My NodeMCUs have AMS1117 3.3 onboard step-down regulator which has a Max Vin of 15 Volts DC (taken from the device spec sheet). I've been bench running a unit at 14 Volts for 24+ hours with no excessive temperature rise, or operational issues.  I in about 50mA, therefore Power dissipation of about 0.6 Watts in the regulator as it's a linear device.

For use in a vehicle where battery charging can push, or even exceed 15 Volts from the vehicle's alternator, this is a 'little close to the wind'. A quick and dirty solution is to stick a couple of rectifier diodes in the supply lead (each will give approx 0.6Volt drop each. Might want to add a reservoir capacitor after the diodes just to smooth things out. (100uF or so.)

Disclaimer:  Use the above info at your own risk, yada, yada. If you don't understand it, don't do it!

hariharan69, 2021-02-26:
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

boards like Arduino and nodemcu all share common voltage regulator called AMS1117 that can support upto 18V its specifically optimized to run in 12v lead acid voltage ranges ie: it cuts of at 10v(min voltage) so go ham and plug a car battery to it :)

CaptainJack42, 2021-04-26:
My experience shows that powering it with ~10.6V will kill the board (after like 15 Minutes of continuous operation) after that the board is only good for using it as a pocket warmer that can be powered by usb or to light up your room using the red and blue onboard LEDs

nilesh-akhade, 2022-09-17:
Sorry, I'm late for the party. But please make it simple for me.

But still, how do I power my NodeMCU 1.0 (ESP-12 E Module) / [LoLin NodeMCU](https://www.make-it.ca/nodemcu-details-specifications/). What are current and voltage requirements? Are there any power modules available?

From my research, I have options:

Voltage: 4.5V-10V or 5V or 3.3V
Current: 500mA or 1A

mbfac, 2022-09-17:
Hi

Vin pin between 4,5 and 10 V MAX  but  5V is better... more safe!

Best regards

nilesh-akhade, 2022-09-17:
That is very helpful @mbfac. The conclusion is
- Vin pin expects anything between 4V to 10V,  500mA - 1A. (5V recommended)
- MicroUSB input expects: 5V, 500mA

RichyT, 2022-10-23:
The regulator on the board is a linear regulator. It has to dissipate heat equal to the current multiplied by the voltage difference. For 5V->3.3V, that's not a lot. For 15V->3.3V, that's going to be a whole lot more (almost seven times as much). It's only a small device with no heatsink.

If you're wanting to run off 12+V and you're doing anything that draws any power, you might want to consider using a beefier regulator to drop the voltage first (15->5 for example) or replace the regulator with something beefier or non-linear like a buck converter.

RichyT, 2022-10-24:
> Looking at the [datasheet](https://github.com/nodemcu/nodemcu-devkit-v1.0/blob/master/Documents/NCP1117ST33T3G.PDF) of the power regulator
>
> Vin should be between 4.75V and 10V

Just to say, I had a look at that datasheet and I think you're misinterpreting it. Though it does seem anecdotally that 10V is the limit.

Closed 2016-02-29.

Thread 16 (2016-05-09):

digitalWrite HIGH & LOW inverted

MutaborLingua, 2016-05-09:
Hello!

Let me get this straight. I bought the following board:
http://www.aliexpress.com/item/Free-shipping-NodeMCU-development-board-for-ESP-12E-from-ESP8266-esp-12E-Lua-IoT-programable-wifi/32583355412.html

I use the Arduino IDE, and everything works pretty much fine. I only have one problem:
If i test it for the blink sketch it reads HIGH as LOW and LOW as HIGH.

Example:
[code]
void setup() {
  // initialize digital pin 16 as an output.
  pinMode(16, OUTPUT);
}

// the loop function runs over and over again forever
void loop() {
  digitalWrite(16, HIGH);   // turn the LED on (HIGH is the voltage level)
  delay(1000);              // wait for a second
  digitalWrite(16, LOW);    // turn the LED off by making the voltage LOW
  delay(100);              // wait for 1/10 second
}
[/code]

This should do (as far as i know) that the LED is on for 1 second and then have a short pause of 1/10 second.
But what the board is really making is the opposite. The LED is off for 1 second following a short blink 1/10 second and so on...
Am I insane or is this plain inverted?

I'm on a mac with Arduino IDE 1.6.8
I use the following bridge drivers:
https://www.silabs.com/products/mcu/Pages/USBtoUARTBridgeVCPDrivers.aspx

Thank you for answers!

rickyitexpert, 2016-06-19:
Same here

pamribeirox, 2016-06-19:
Some of those boards have the LED connected to VCC, probably because the MCU can sink more /the needed) current in the I/O pins at lower level.
This way, the LED only lights in the LOW state of the pin when it outputs about 0V

tabvn, 2016-07-02:
I got the same issue , set LOW led is on.

and  digitalWrite(relayPin, HIGH); // Led OFF i tested both on D0// 16 , and D7 // 13

very confusing about this ?

pathob, 2016-09-04:
This is the wanted behaviour. If the LED would need a current of 20 mA for full brightness and you would connect the anode of the LED to the GPIO, the GPIO couldn't provide the needed 20 mA, as it can only provide 12 mA.

If you turn it vice versa and connect the cathode to the GPIO and the anode to the main 3.3 volts power supply (which should be able to provide about 800 mA of current), you can reach the full brightness (and save your GPIO). But then, the LED lights up, when the GPIO is set low.

tabvn, 2016-09-05:
Thanks for your information that helped. @pathob

speeddragon, 2017-01-24:
Just to be clear, is normal for every Digital PIN do be inverted or just the pin LEDs ?

Trafitto, 2017-07-17:
Same problem with digitalWrite(ledPin, 0); //Turn led ON

mharmon12, 2017-08-14:
Very common practice to do this.
An I/O typically sinks more current than it can source.

Find a schematic for the LED on the circuit board you are using and you'll see how it's biased for the I/O.
Writing a "1" to that port doesn't mean turn the LED on, it means write a "1" to that port.

If this is difficult for you to remember then there are ways around the confusion.
I use sharp defines in my code to create pseudonyms to add clarity.

Someone once said that good code reads like a story.

Coding in C is not an elegant story...
The following code looks more like telling your pet to do a trick.
I address my pet (he knows I'm talking to him) then the trick I want the pet to do.

// My pet's name
#define Red_LED 16

// My pets mode
pinMode(Red_LED, OUTPUT);

// Your pet's tricks
#define turn_On 0
#define turn_Off 1

digitalWrite(Red_LED, turn_On);
digitalWrite(Red_LED, turn_Off);

You could get really crazy and write a function...

void RED_LED( string action ){
    if( action == "ON" )
        digitalWrite(Red_LED, turn_On);
}else{
        digitalWrite(Red_LED, turn_Off);
}

RED_LED("ON");
RED_LED("OFF");

I would dig into the pins_arduino.h file and see if there is a definition for the LED on that GPIO and use that reference. It's a good practice to do that because it makes your code more portable.

NarinLab, 2017-09-15:
How can i make my external led that also connected to GPIO16 turn on and turn off in sync with my internal red led?

My brain can not process this logic.  When i set my external led off, my internal led is on... and they both can not do what i say. pinMode(16, OUTPUT) and digitalWrite(16, LOW) also not working, i mean, may be i can turn the external led on just like the internal one by connecting the external led anode to 3.3v rail and cathode to pin 16 with that piece of code, but... its just not working.

Please help me.

NarinLab, 2017-09-15:
I'm sorry, problem solved. My imperfect sensor in my face didnot see the NodeMCU pin is not really click to breadboard. This silly things make me crazy for six hours.

The code is right, just need to push the Node to breadboard. hahh....

mharmon12, 2017-09-15:
Best fix ever!
You have learned more than you know from this exercise.
Thank you for updating.

Raincode, 2019-04-20:
Thank you! I spent waaaay to long being confused as hell before googling it...

amitabheer, 2019-08-22:
Dear All,
Greetings and thanks to everyone's contribution here.
Kindly acknowledge that I too have facing this kind of problem with NODE MCU Lolin V3.
I have made a project on 8_Ch relay control via Alexa (via Sirin and Alexa). Everything is working well but all outputs are inverted. After uploading program to MCU the default output in ON (HIGH) for all 8 Channels (Pins 5,4,0,2,14,12, 13 and 15).
Even after lot of thinking I could not understand why its happening to this and how can the same be resolved?
I think this output can be inverted by changing (inverting) the Outputs 0 to1 and vice-versa but this doesn't seem good to me as the MCU (and my circuit as well) should behave as it was designed for.
So, all of you are requested to suggest me to attain the solution.
Thanks and regards!
-Dr Amit

vikrantsingh47, 2020-05-19:
found this article which explains it in detail: https://www.dataq.com/blog/data-acquisition/whats-all-this-sink-and-source-current-stuff/

lokaero, 2021-03-22:
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

lokaero, 2021-03-22:
After searching about this for a while.. i found the reason for this kind of behaviour in ESP8266 board..
The problem is When we give digital-write HIGH the output is LOW.. and LOW is given out as HIGH.

Solution for this problem is....
The pins highlighted in green are OK to use as output  and input(RECOMMENDED)... The ones highlighted in yellow are OK to use, but you need to pay attention because they may have unexpected behaviour mainly at boot this is also the reason why ESP8266 behaves inverted to digital in and out and reboots automatically after sometimes. The pins highlighted in red are not recommended to use as inputs or outputs.

So please use the correct GPIO pins for input and output..try to use pins that are marked green only....thank you..

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

mrnams, 2021-09-17:
Once we give low input to pin 16 of NodeMCU ESP8266, it remains low, see my code below which is not able to switch off led because of this issue, can't we use pin 16 as general purpose input?
See my complete code
https://github.com/mrnams/IOT/blob/main/ESP8266/Examples/Basic/One-Led-Two-Push-Buttons

chess-levin, 2022-01-14:
Hi guys, have a look at this great post https://www.instructables.com/ESP8266-Using-GPIO0-GPIO2-as-inputs/
I think it is great explanation of this special topic at the GPIO pins 0,2,15 of ESP8266 and how to use them and how you can still use them.

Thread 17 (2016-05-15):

ESP8266 destroyed

CipTGCN, 2016-05-15:
Hi,

I have managed to burn 4 ESP8266 on a dev. board (https://github.com/nodemcu/nodemcu-devkit-v1.0), and the reason is still unknown for me.

The history is like this:
After I have burned the:
– 1st one I removed GPIO10 from my code an also let if floating,
– 2nd I have reduced the current for driving MOC3041 from 15 to 7.6mA,
– 3rd I removed the ADC In setting (analogRead) from my code, even if I don
t use it for anything, yet.

Now I have the following circuit:
220V AC -> Power transformer from 220 to 6V (AC) -> Rectifier bridge (Vout ~8.6V DC) -> 2 capacitors (470uF + 100nF) -> LM7805 -> Power the ESPshield to Pin 15 (+) and Pin 7 (-) -> use Pin8/GPIO14 as an output to power an opto-triac MOC3041 (current was limited to 7.6mA using a 270ohm resistor) ->a triac to drive a load of 21W (7 x AC LED lamp) -> Pin1/GPIO16 used as an input (if pin state is changed than also the output is changed).

After running the application ~15 minutes (Playing on/off via web requests) I have played also a little bit with the input pin and everything worked as expected. Then I have decided to let lamps ON (input pin was pulled to GND - Red led from shield lit), but after ~5 -10 minute the lamps turned off (Red led from shield remained on) and now the 4th ESP is dead.

I have checked the value of current limiting resistor for the Red Led (470 ohm, value was obtained after I have removed the resistor from the shield) and from my calculations the current ~3.2mA is small enough not to damage the ESP, and now I have no idea what I
m doing wrong.
If you think that is relevant I can provide also the code (written using Arduino IDE)

Have anyone an idea that can help me with this issue?

iandrosov, 2016-05-23:
What in your description indicates that you "Destroy ESP8266"? One thing I see in your schematic, you are using 5V to power NodeMCU, form what I read in docs recommended power is 3V although there is a pin-out you seem to be using that can run this unit at 5Volts I would try to reconfigure to use 3V or USB power to test. Unless you have requirement to run this at 5V.

CipTGCN, 2016-05-23:
The value of the power supply is in the safe range:

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

supersjimmie, 2016-09-07:
No, as far as I can see he connects +5V to the 3.3V pin, not to the 5V pin.
The 5V pin (VDD 5V) goes through the onboard 1117-3.3V regulator but the 3.3V pin he is using goes straight into the ESP chip. The chip will die because 5V on it's 3.3V pin is too much.

CipTGCN, 2016-09-07:
From schematic PIN 15 is 5V VDD
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

https://github.com/nodemcu/nodemcu-devkit-v1.0/issues/17#issuecomment-245269701

fiedlfa, 2016-09-07:
From your Schematics it looks a bit that you don't Connect Ground of the NodeMCU. Is this an Error in your Schematics?

CipTGCN, 2016-09-07:
My block diagram is not 100% precise..the GND pin used is pin 7 from the "right" side.
I have to say that all the time the entire pcb was near (5-10 cm) a bunch of wires powered with 230V  AC  (@ 60Hz)

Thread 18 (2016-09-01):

North American Wholesaler

Jonathan411, 2016-09-01:
This is a non-technical issue, but may be an issue that others are encountering.

Our company, located in Canada, would like to make volume purchases of "official" (i.e. Amica) NodeMCU V2 modules.  However, we have been unable to locate a Canadian, or even US-based, wholesaler.

Can anyone provide contact information for a North American wholesaler of "real" Amica modules? (we don't want to purchase "knock-offs" for use in commercial products).

Thank you.

marcelstoer, 2016-10-12:
@nodemcu @vowstar @GerwinJanssen can you help out Jonathan?

Jonathan411, 2016-10-12:
Thanks Marcel, but I have located a Chinese supplier that can supply NodeMCU dev kits in volume, for less than $3 US per piece.  If you, or anyone you come across, is looking for a volume supplier of these units let me know and I will forward the Chinese contact information (contact was made via Alibaba.com).

FYI:  we are using the NodeMCU dev kit, instead of just the ESP8266 module, because we can’t build/assemble the power circuitry, CP2102, micro USB connector and ESP8266 module for anything close to $3 in North America. It’s an incredible platform for $3 - we are just soldering the entire dev kit onto our custom pcb (along with other components) to create the final product.

Thanks again,

Jonathan

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

themendes, 2016-10-13:
@Jonathan411 I am certainly interested. Could you please put me in touch with the relevant person? US$3 is remarkably cheap.

Jonathan411, 2016-10-13:
Hi,

To get the $3 unit price we are placing orders for thousands of units at a time, on a monthly basis, and we are also purchasing (by the thousands) cables and power supplies.  If you have a requirement for thousands of units at a time send me your contact information and I will forward it to our supplier.  If your requirement is for a lower volume, send me your estimated requirements and I will ask our supplier if they will handle smaller orders.

Jonathan

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

vowstar, 2016-10-13:
@Jonathan411 If you need NodeMCU devkit or modules, you can contact the factory of AiThinker(http://www.ai-thinker.com) in China, They produce all kinds of ESP modules and boards. They also have agents around the world.

Jonathan411, 2016-10-13:
Thanks for the link!

Jonathan

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

Jonathan411, 2016-10-13:
If you are looking for smaller volumes AI Thinker uses the following online store:

https://world.taobao.com/search/search.htm?_ksTS=1476361384777_41 <https://world.taobao.com/search/search.htm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> &spm=a21bp.7806943.20151106.1&_input_charset=utf-8&navigator=all&json=on&q=nodemcu&callback=__jsonp_cb&cna=iRadD11YxXwCAUxFEAlO84v9&abtest=_AB-LR517-LR854-LR895-PR517-PR854-PR895

Prices for nodemcu modules seem very reasonable.

Jonathan

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

tablatronix, 2017-03-23:
I wish you could buy them without headers soldered, like other dev kits do.

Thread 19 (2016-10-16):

Eagle library for Nodemcu Lolin V3

irwanayeah, 2016-10-16:
Hello gentleman,
I would like to use Nodemcu Lolin V3 as a part in my PCB layout. But I can't find any library for Eagle. Is there any existing one? Or does anybody plan to create one?
Thanks.

sturze, 2017-08-11:
me too! still nothing... nowhere...

vowstar, 2017-08-11:
@irwanayeah @sturze Hello, Lolin V3 is not official board, the official latest board is nodemcu-devkit-v1.0
And, we don't authorization Lolin V3 use the name Nodemcu.

Eltronas, 2017-11-08:
https://mega.nz/#!1t8jzSqb!doaTLDcj8MVNFQ1ReJRFOIpOO0-HCy4FIjuXTIL_IVw

I create one, I hope I've helped :)

cmedinam, 2018-01-22:
Eltronas I thing your package is wrong, Its weight is wrong or there are diferent sizes of the "same" board.

shasan247, 2018-01-29:
Eltronas, do you have any library for V2???

patavium73, 2018-03-04:
guardate questo che funzina https://www.arduinotronics.com/nodemcu-lolin-v-3-eagle-library/

HADIUU07, 2024-01-07:
> guardate questo che funziona https://www.arduinotronics.com/nodemcu-lolin-v-3-eagle-library/

can you sent link again ? the link expired

Closed 2017-08-11.

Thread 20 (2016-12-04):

Please link good USB-->UART driver

bakroistvan, 2016-12-04:
Please link good USB-->UART driver

NandikaSirinuwan, 2017-02-09:
http://www.silabs.com/products/mcu/pages/usbtouartbridgevcpdrivers.aspx

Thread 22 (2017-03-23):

PTC footprint for better protection

tablatronix, 2017-03-23:
I would love to see PTC protection, or at least a footprint for it, instead of just the schottky ( which will magic smoke on direct short real quick btw ) :smile:

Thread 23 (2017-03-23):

feature usb headers/inputs

tablatronix, 2017-03-23:
usb header breakout support, D+ D- inputs for usb etc. even if they were 2mm pitch holes or pads.

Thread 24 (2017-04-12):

MAC AIR and USB PORT not showing up with NODEMCU CP2102 (1.0)

XicoBHZ, 2017-04-12:
Guys, can you help me. I've just got my NODEMCU ESP-12e with CP2102 (1.0), I'm using a MAC AIR, but the device doesn't appear on the PORT list, as some of the guys above. I'be tried different cables as well a USB interface that allows me to input an extra 5V DC PSU to feed the NODEMCU, no response at all. The Blink sketch compiles OK, the board is correctly set for NODEMCU 1.0 (ESP-12e Module), but no way to make it works. I heard that I should download a driver for CP2102, is it right? If so, where can I find it? Any help? Thanks!

vowstar, 2017-08-11:
You can use homebrew install it.

Press Command+Space and type Terminal and press enter/return key.
Run in Terminal app:
ruby -e "$(curl -fsSL https://raw.githubusercontent.com/Homebrew/install/master/install)" < /dev/null 2> /dev/null ; brew install caskroom/cask/brew-cask 2> /dev/null
and press enter/return key. Wait for the command to finish.
Run:
brew cask install silicon-labs-vcp-driver

http://macappstore.org/silicon-labs-vcp-driver/

Closed 2017-08-11.

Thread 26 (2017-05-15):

Very low power

moozoo64, 2017-05-15:
As per https://tinker.yeoman.com.au/2016/05/29/running-nodemcu-on-a-battery-esp8266-low-power-consumption-revisited/

It would be great it the usart used its own 3.3V regulator
https://yeomanblog.files.wordpress.com/2016/05/option2schematic.jpg
Plus a TX pull down resistor.
This is so it doesn't consume power while not in use.

It would be great if there was a jumper to disable the AMS1117 so that an external battery + MCP1700 + 1000uf Electrolytic could be used instead (for burst transmission of sensor data).

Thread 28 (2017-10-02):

A0 adc limit input?

johndoe71rus, 2017-10-02:
what are the limits of the voltage A0? Usual esp-12x up to 1v, you use a resistive divider at the input.
can i measure li-ion battery voltage?

vowstar, 2017-10-02:
No, you can't use it to measure li-ion battery directly. You'd better use an amplifier to convert the voltage.

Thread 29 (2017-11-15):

Connect relay board to NodeMCU

alexartd, 2017-11-15:
Hello, I've a relay board with 3 pins, VCC, GND and IN. I've connected VCC to 3.3 and GND to GND of MCU. In is connected to a GPIO pin. With pinMode(pin, OUTPUT); and digitalWrite(RELAY1,LOW); and digitalWrite(RELAY1,LOW); relay doesn't work. I've tested that if I connect relay IN pin to VCC it doesn't work but if I connect it to GND it work. This relay hasn't jumper to set if it should work in HIGHT or LOW. I suppose that MCU GPIO should provide a GND signal to turn on relay but I don't know how.
Can you help me ?

mB-PiBox, 2017-11-15:
Probably not supplying the correct pinout. Also you would need to define "RELAY1" to the pin you're using.

Relay works with a ON/OFF. Supplying power to pin X connected to "IN" turns relay off if you have pin set to output

alexartd, 2017-11-15:
If I connect led anode (+) to the same GPIO and led catode (-) to GND it works so GPIO is controlled correctly, but if the same GPIO is connected to IN pin of relay, it doesn't work.

mB-PiBox, 2017-11-15:
http://bfy.tw/F33K

alexartd, 2017-11-15:
Many thanks but it is what I've done and I'm sure that relay is connected well, as explained on internet. You haven't understand my question. I think that the problem is that this relay board work with low signal, GND to be clear. But a GPIO is not able to send a GND signal bit a positive signal from 0 to 3.3V. I think that with a transistor I can resolve but I'm searching other solutions.

mB-PiBox, 2017-11-15:
No, relays work the same. You have POWER or NO POWER to the input/trigger. Which Opens or Closes the gate/circuit depending on the NC/NO state of the relay.

alexartd, 2017-11-15:
Ok but I've wrote that if I connect a led in the place of relay, it work so GPIO work.

alexartd, 2017-11-15:
I think this is the solution:
https://iot-playground.com/images/articles/053/ESP8266_4_relay_switch.png

mB-PiBox, 2017-11-15:
Again, relay works the same. I have a 8 RELAY system that controls the lights in my work shop off a NodeMCU, and each relay input/trigger is connected to a GPIO. No need for any resistors (or in the case of the link you provided NO transistor) to make the relay work.

I even  have a 2 channel relay sitting right here, that I just tested on a spare NodeMCU, and again no resistor or transistor needed.

alexartd, 2017-11-15:
Probably my relay is different from your. I don't know.

mB-PiBox, 2017-11-15:
THEY ALL WORK THE SAME! FFS

alexartd, 2017-11-18:
My relay turn on with pin IN connected to GND or also to 3.3V. GPIO pin from MCU turn from 0V to 3.3V but I don't understand why it cannot turn on relay. I've solved with circuit with transistor.
Bye

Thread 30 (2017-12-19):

Gerber file latest version

manibenwa, 2017-12-19:
Hai ,

We are developing Nodemcu board and this github has 4 gerber files related to the Nodemcu board
which one should i select or which is the  latest version gerber file???

vowstar, 2018-01-02:
It is better to use the PCB source file, not gerber file. I think the latest gerber file is in master branch of this reop, but the most latest gerber file you'd better generate from PCB source file.

manibenwa, 2018-01-02:
Thanks for replay,
Where are the PCB source files ?? I haven't found the PCB source files in https://github.com/nodemcu/nodemcu-devkit-v1.0 link!!
Please help me....

vowstar, 2018-01-03:
https://github.com/nodemcu/nodemcu-devkit-v1.0/blob/master/NODEMCU_DEVKIT_V1.0.PcbDoc

This file is the PCB source file, please use Altium designer to open it.
All this project is open source and in this repo.

manibenwa, 2018-01-03:
Thanks VOWSTAR

manibenwa, 2018-01-10:
Hai,
           I found the BOM of this board in this link  https://github.com/nodemcu/nodemcu-devkit-v1.0/blob/master/NODEMCU_DEVKIT_V1.0.PDF. I need voltage rating of capacitor and wattage rating of resistors.could u tell me is there any possible way to get the ratings of this capacitors and resistors????

vowstar, 2018-01-10:
The parameters we actually use is

|Designator|parameter|
|-|-|
|C1,C4,C6 |100nF (104) ±10% 16V|
|C2 |100uF(107) ±10% 6.3V Case B 3528|
|C3,C5,C8 |10uF(106) ±20% 10V |
|C7|10uF(106) ±10% 25V|
|D1|SOD-123 40V,1A,VF=0.45V@1A|
|LED1|1.6x0.8x0.6 Iv= 35~65mcd @IF=5mA ESD:1000V |
|R1,R2,R3,R4,R5,R7,R8|12KΩ (1202) ±1% 0.0625W [50V TYP] [100V MAX] T.C.R ±100|
|R6,R9,R11,R12|470Ω (4700) ±1% 0.0625W [50V TYP] [100V MAX] T.C.R ±100|
|R10(Do not install)|0Ω (0R00) ±1% 0.0625W [50V TYP] [100V MAX] T.C.R ±100|
|R13|220kΩ (2203) ±1% 0.0625W [50V TYP] [100V MAX] T.C.R ±100|
|R14|100kΩ (1003) ±1% 0.0625W [50V TYP] [100V MAX] T.C.R ±100|

manibenwa, 2018-01-10:
Thanks vowstar.
if u have part numbers it is really help for me.

manibenwa, 2018-01-10:
Hai,
 does nodemcu have next version??if their send me some information ..

vowstar, 2018-01-11:
@manibenwa I'm taking part in the design of an AI chip, next open hardware project may be something about AI chip.

manibenwa, 2018-01-24:
Hai vowstar,
        Iam using NodeMCU DEVKIT V1.0.
        I would like to power the nodemcu board without usb. I want power up the  board  with battery
       (5v or 12v).is vin pin is used to power the board with external battery ??

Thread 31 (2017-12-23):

proteus design for circuit design

Amanrazdan, 2017-12-23:
i was trying make circuit design with nodemcu with proteus software but couldn't find the include libraries to work with it in the proteus software. Can any anyone help.

alanrivetta, 2018-03-04:
Is there anything new about this?

I have a NODEMCU with Arduino IDE and I would like to simulate it in Proteus.
Is there any way to get it?

PriyankBasrani, 2018-05-16:
Can you send me library of NODEMCU alanrivetta??

maresfrios, 2018-05-21:
Can you send me too library of NodeMCU ?
maresfrios@gmail.com  @alanrivetta

DavidHolo, 2018-10-09:
me too please ?  @alanrivetta or another else ?  @PriyankBasrani @maresfrios
fikrifarhanrrasyid16@gmail.com

omarmhamza, 2019-07-20:
Here you go @DavidHolo @maresfrios @PriyankBasrani @alanrivetta @Amanrazdan

http://www.mediafire.com/file/5zcbljfw9zbzc25/NodeMCU_for_Proteus_%2528Arduino_Magix%2529.rar/file

aasitvora99, 2021-08-01:
I guess we have to interface with an arduino and then run the code off arduino. Only then it'll work.
But if someone has any answer please do help out.

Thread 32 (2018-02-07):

Schematic from V3

sch0bert, 2018-02-07:
Hello,

I have been trying to find the NodeMcu V3 schematic through the web but with no luck. Does anybody has it?

Regards,
Pascal.

liquidrinu, 2018-03-24:
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

ccoenen, 2018-12-31:
The pinout is a good start, but it would be helfpul to see the actual net plan/schematic, so we know what else is on that pin. Something like this, but for v3:

https://raw.githubusercontent.com/nodemcu/nodemcu-devkit/master/Documents/NODEMCU_DEVKIT_SCH.png

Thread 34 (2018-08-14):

Nodemcu board could not handle 16v ?

mmaxus35, 2018-08-14:
I have bought a esp8266 nodemcu board, yet it is burned and smoked out when i connect 16v to Vin pin and GND to GND ?  Diodes are burned as it is shown in the figure  ?

I could not understand why ? Because diodes and AMS1117 has maximum power input rating as much as 18V ?
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

MStylesMS, 2018-08-14:
Most devkits have a max input voltage closer to 5v.  A very few can handle up to 12v, but those get fairly warm.  It’s the other components, mainly the voltage regulator, that limit it.

Mark Stevens

Sent from my iPhone
All typos are Siri's fault!

On Aug 14, 2018, at 6:15 AM, mmaxus35 <notifications@github.com<mailto:notifications@github.com>> wrote:

I have bought a esp8266 nodemcu board, yet it is burned and smoked out when i connect 16v to Vin pin and GND to GND ? Diodes are burned as it is shown in the figure ?

I could not understand why ? Because diodes and AMS1117 has maximum power input rating as much as 18V ?
[nodemcu]<https://user-images.githubusercontent.com/22351514/44088620-82a4e3f8-9fcc-11e8-9770-547b4b206da5.jpg>

—
You are receiving this because you are subscribed to this thread.
Reply to this email directly, view it on GitHub<https://github.com/nodemcu/nodemcu-devkit-v1.0/issues/34>, or mute the thread<https://github.com/notifications/unsubscribe-auth/ATsI7E8sC4469IDNBdnkSbqhuiBRa4w1ks5uQrFggaJpZM4V8PqV>.

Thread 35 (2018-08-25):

Voltage peaks in nodeMCU

jdelrio810, 2018-08-25:
Hi, I am measuring the current consumed by a NodeMCU, connect a resistance of 1 ohm in series with the power supply and there are peaks of 200mV every 100ms that these peaks are due.

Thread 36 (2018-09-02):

Output Current of Digital Pins

PeterESP8266, 2018-09-02:
I`m not sure this is Issue worthy so lease delete when not:

I'm trying to power the waterproof version of the DS18b20 Temperatur Sensor via the D1 (GPIO05) Pin.

I tested the setup first by using the 3.3 Volt Out Pin and by connecting a 4.7 Resistor between VCC and the Data Pin (GPIO04) and everything worked.

Now when I'm trying the same setup but with the D1 (GPIO05) Pin instead of the 3.3 V I only get the 85 °C Error reading as if it's not properly wired.

GPI05 puts out 3.3 V when set high so that should work. I also tried the setup with different sensors like the HR-SR04 Ultrasound and the DHT-22. They all work fine.

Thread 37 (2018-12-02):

Node mcu stop working and start blinking on board led

Zinthos, 2018-12-02:
I program it with blynk examples using audrino IDE to perform with blynk app
at first it work fine by powering with usb
Then I try to power it from Vin pin and GND with 9v battery after that it's no longer working and not even wiith usb.The Led on the board blinking all the time :@
I can't buy a new one :'(

Jivansha, 2019-03-15:
Have you tried resetting the MCU? Try pressing the reset button a few times before uploading again.

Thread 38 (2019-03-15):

Failure of the Reset circuit of the NodeMCU

Jivansha, 2019-03-15:
Hi, I have been using the nodemcu V3 for a week before the reset switch failed. It seems the nodemcu only works if the reset switch is kept pressed otherwise not. What might be the possible error? Also is there any way it can be rectified?

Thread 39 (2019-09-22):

Arduino crashing on Mac, nodemcu ESP8266 doesn't connect issues Siliconlabs SI driver doesn't work

sabeeh125, 2019-09-22:
Wow. this was a mission.
I'm on a Mac Sierra 10.12 with an ESP8266.

First, Arduino kept crashing.
Crash errors: nsinvalidargumentexception and setAutomaticCustomizeTouchBarMenuItemEnabled

It took probably 10 tries of installing different versions but Arduino keeps crashing
SOLUTION:
https://www.arduino.cc/download_handler.php?f=/arduino-1.8.7-macosx.zip

THEN I tried what felt like every SI Silicon Labs driver under the sun including the one that came with the manual to my ESP8266. DIDN't WORK. Tried quitting, restarting, updating java, different MicroUSB cables and followed this thread as well: https://github.com/nodemcu/nodemcu-devkit-v1.0/issues/2

FINALLY here's the solution I found. The SI (cu.SLAB_USBtoUART) driver doesn't work, this one WORKS. Load it up.

SOLUTION:
http://blog.sengotta.net/wp-content/uploads/2015/11/CH341SER_MAC-1.4.zip

georgalis, 2019-09-22:
sabeeh125, thanks for letting us know how much effort you have exerted.
otherwise we wouldn't know about any problems! Next time you solutions
would be more valuable
if you included any kind of controls and output information. For example,
this is not an Arduino list,
but if I were to consider your archival posting, it would be important for
me to know the revision of
your hardware, the versions of the failed images you tried, and a more
specific crash report, console,
logs, etc.

The crashy binaries you used almost certainly worked on different hardware,
but for future development,
or another user at a different time, there is not any info in your post
about the circumstance which make
your links the right choice, or any information a developer could use to
fix the problems your encountered.

although you provided the word "solution" in your post, it reads more like
a rant because there is no accountability
of your solution (the hardware revision, software revision or specific
bugs). Not sure how a developer,
or user could make effective use of your post.

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

--
George Georgalis, (415) 894-2710, http://www.galis.org/

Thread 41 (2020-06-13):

HTML server down after a while (STA mode)

magoblin, 2020-06-13:
Hello!
I have my first ESP8266 module (NodeMCU 1.0) and I was able to make a HTML server on AP and STA mode.
So the next level was keep the server in STA mode working as much as possible on my home network so whenever I need the data acquired by a temperature and humidity sensor (I2C) I could connect by any device and get it on the browser.
It works great, but then I noticed that after a while the server did not answer my requests, ene the ping did not have answer from the ESP. As soon as I reset the board I get the webpage right away.
At this point I have not any clue about what happens but then I wondering if the ESP or WI-FI module was on a kind of “sleep mode”.
The loop works fine since I included a routine that shows the parameters (temperature and humidity) whenever I push the “flash” button. It works perfect so included a routine to reconnect the module to my network.
So I left the board connected to a 5V phone charger (1amp) overnight and after 30 minutes all works fine but on the middle of the night I try to retrieves the data and again the HTML server was not available. I push the button and the browser shows me the data.
The router is stable, the IP of the ESP does not matter if is assigned by the router or I set it out manually.
I guess something is going to sleep without I instructed to do so.
Anybody has experienced the same issue?
I have googled it and I found some very old forum but with no conclusion. They made a workaround with “thiker” function.
Please tour comments, ideas and if someone found the reason and have a solution....even better!!!

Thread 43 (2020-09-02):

GPIO14 pin (D5) not working

anidh1997, 2020-09-02:
Hi everyone,

I am using NodeMCU Amica. It has UART communication with GPS sensor, pin D5(Rx) is connected the GPS_TX and getting data with SoftwareSerial library. The problem coming is, If I connect the power to NodeMCU when the UART pin is connected, the data does not comes. But if the UART pin is connected after connecting the power to NodeMCU, the data comes. This problem is not at the other pins of NodeMCU (Eg.  D2). Are there some specifications related to D5 pin?

The pin-name of D5 is MTMS as given in NodeMCU ESP8266 datasheet.

I checked the schematic "NODEMCU_DEVKIT_V1.0.PDF" in this GitHub page and found MTMS written in red (please see the attached picture) but unable to understand what it means.

If anyone knows about the above problem please help.

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

jcallano, 2020-09-02:
You can read this article that investigates the state and behavior of each GPIO on boot:

https://rabbithole.wwwdotorg.org/2017/03/28/esp8266-gpio.html

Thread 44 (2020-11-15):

Pinout Documentation

mrleongalaxyum, 2020-11-15:
Hello,
Since I'm not able to send you an email, I'll try contacting you this way.
I'm interested in software/template you used to generate the following pinout image:

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

I'm currently working on a LoRaWAN node device which will have quite a bit of headers so I'm interested in creating a similar pinout graphic.

Best regards,
Leon

vowstar, 2020-11-15:
[NODEMCU-DEVKIT-V1.0-INSTRUCTION-EN.zip](https://github.com/nodemcu/nodemcu-devkit-v1.0/files/5541772/NODEMCU-DEVKIT-V1.0-INSTRUCTION-EN.zip)

This was a very old story. In the past years I use M$ word. Now I'm using draw.io

mrleongalaxyum, 2020-11-15:
Thanks a lot!

Closed 2020-11-15.

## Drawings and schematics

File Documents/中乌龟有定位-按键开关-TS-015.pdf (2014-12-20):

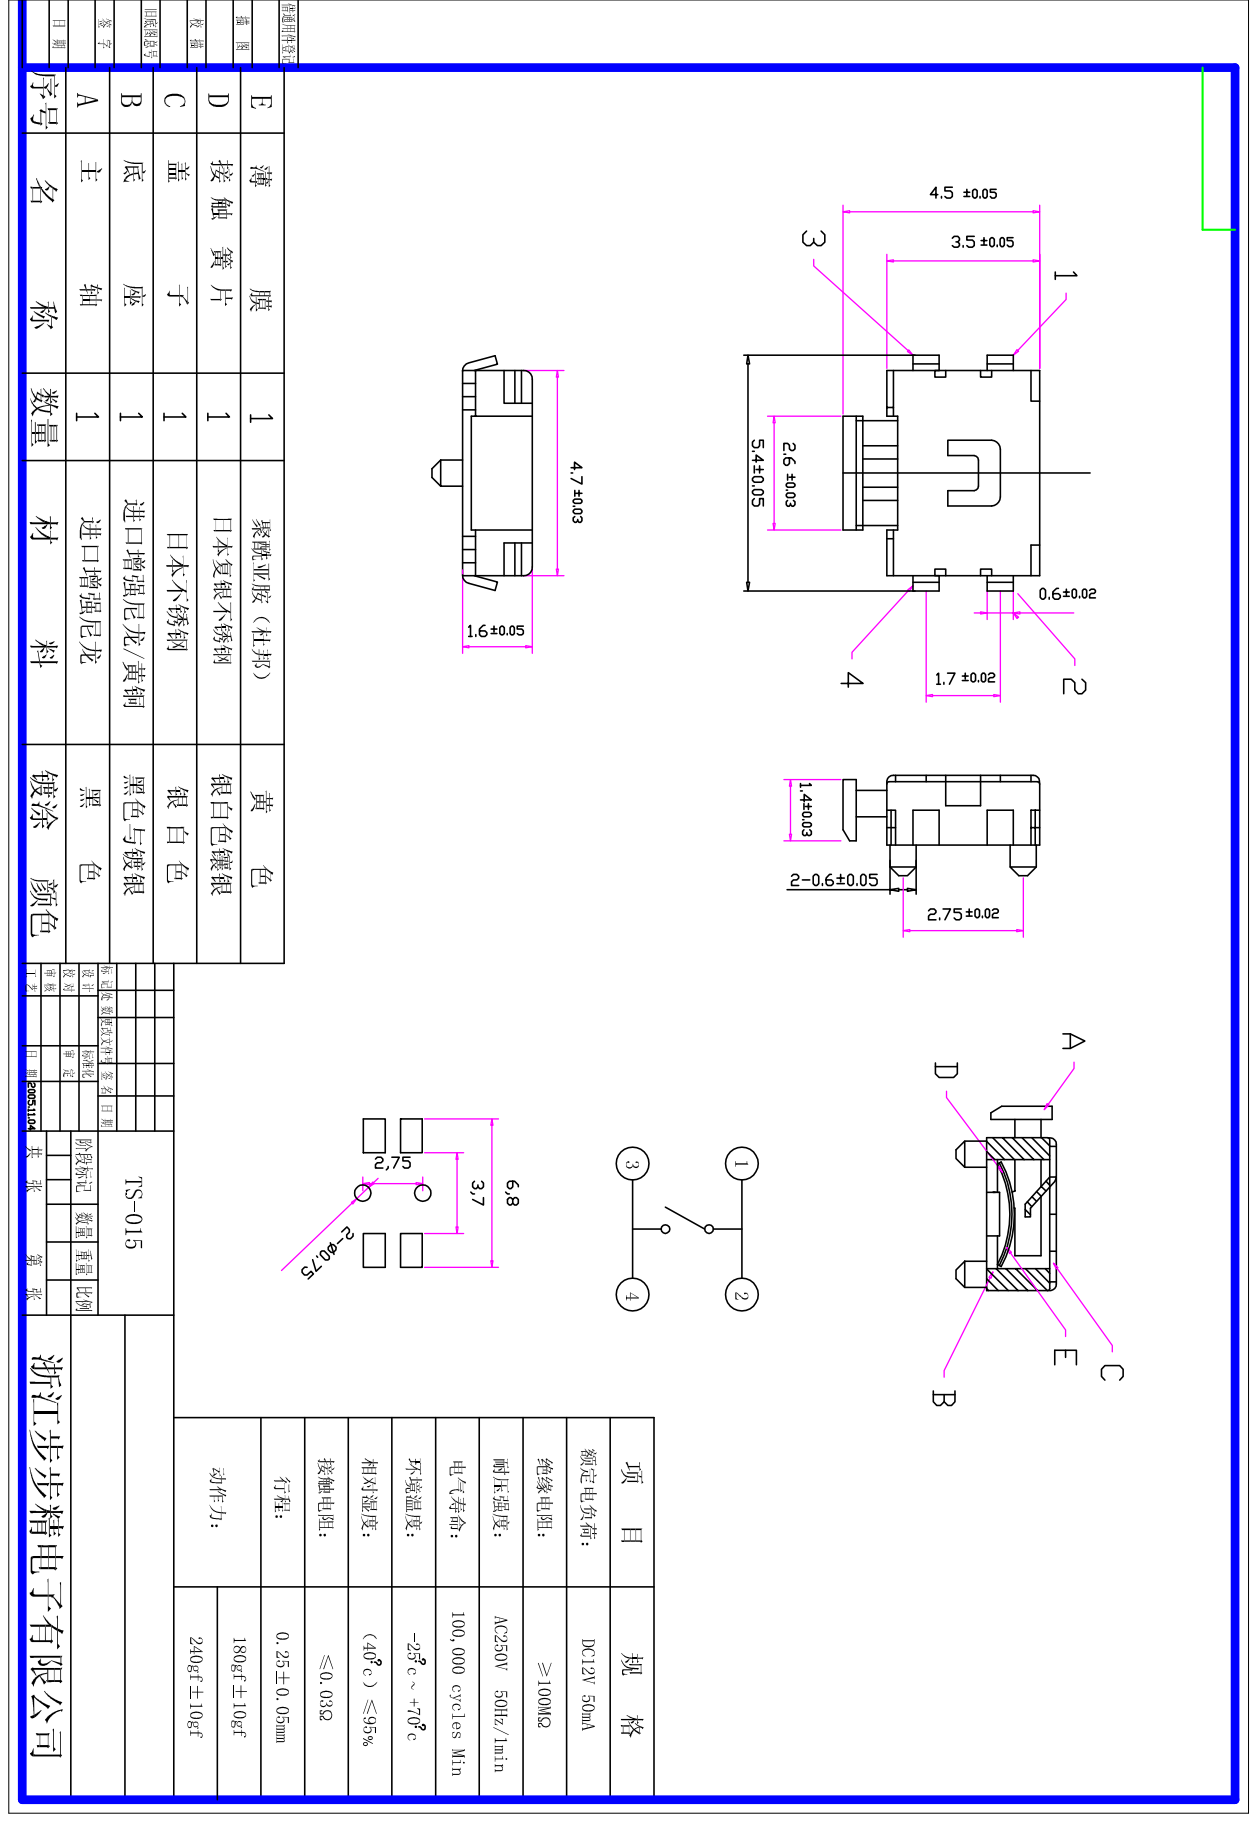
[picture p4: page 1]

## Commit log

2014-12-01 Initial design.
    [NODEMCU_ESP12.PcbDoc, NODEMCU_ESP12.PrjPCB, NODEMCU_ESP12.SchDoc]
2014-12-03 Use capacitor do AUTO DOWNLOAD.
    [NODEMCU_ESP12.PcbDoc, NODEMCU_ESP12.PrjPCB, NODEMCU_ESP12.SchDoc]
2014-12-04 NodeMCU with triode Auto program circuit
    [NODEMCU_ESP12.PcbDoc, NODEMCU_ESP12.PrjPCB, NODEMCU_ESP12.SchDoc]
2014-12-04 Changed the bottom overlay
    [NODEMCU_ESP12.PcbDoc]
2014-12-05 Fixed some PCB layout
    [NODEMCU_ESP12.PcbDoc, NODEMCU_ESP12.PrjPCB, NODEMCU_ESP12.SchDoc]
2014-12-06 Change triode to S8050
    [NODEMCU_ESP12.PcbDoc, NODEMCU_ESP12.PrjPCB, NODEMCU_ESP12.SchDoc]
2014-12-07 Add capacitor and pull up resistor to RST pin, make it more stable.
    [NODEMCU_ESP12.PcbDoc, NODEMCU_ESP12.SchDoc]
2014-12-07 Add D0~D10 to schematic.
    [NODEMCU_ESP12.PcbDoc, NODEMCU_ESP12.PrjPCB, NODEMCU_ESP12.SchDoc]
2014-12-20 Add documents and gerbers.
    [Bill of Materials-NODEMCU_ESP12.xlsx, NODEMCU_ESP12.PcbDoc, NODEMCU_ESP12.PrjPCB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]
2014-12-20 Moved the M7 diode.
    [NODEMCU_ESP12.PcbDoc]
2014-12-23 Update README.md
    Add description of micro USB cable.
2014-12-28 Due to ESP-12's change, DEVKIT swapped GPIO4 and GPIO5.
    [NODEMCU_ESP12.PcbDoc, NODEMCU_ESP12.PrjPCB, NODEMCU_ESP12.SchDoc]
2014-12-28 Synchronous all documents with sch.
    [NODEMCU_ESP12.PrjPCB]
2014-12-28 Add NODEMCU-DEVKIT-INSTRUCTION. Update PIN MAP.
2015-01-21 Update 3D body of ESP-12.
    [NODEMCU_ESP12.PrjPCB]
2015-01-28 Update devkit to V1.0
    [01_SYSTEM.SchDoc, 02_ESP12_CORE.SchDoc, 03_USB_TO_UART.SchDoc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]
2015-01-28 Renamed file name.
    [NODEMCU_DEVKIT_V1.0.PcbDoc, NODEMCU_DEVKIT_V1.0.PrjPCB, NODEMCU_ESP12.PcbDoc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]
2015-01-31 Move NCP1117ST33T3G_PDF.PDF to NCP1117ST33T3G.PDF
    [NODEMCU_DEVKIT_V1.0.PcbDoc]
2015-02-05 Update distance of Pin and Holes.
    [NODEMCU_DEVKIT_V1.0.PcbDoc]
2015-02-05 The placement is complete, but the layout isn't complete.
    [NODEMCU_DEVKIT_V1.0.PcbDoc]
2015-02-07 Add NODEMCU-DEVKIT-V1.0-INSTRUCTION-EN.pdf
    [02_ESP12_CORE.SchDoc, NODEMCU_DEVKIT_V1.0.PcbDoc]
2015-02-07 Unroute the net.
    [04_POWER.SchDoc, NODEMCU_DEVKIT_V1.0.PcbDoc]
2015-02-07 Replace M7 to SS14 to make NCP1117 have safe voltage drop.
    [04_POWER.SchDoc, 05_IO_CONN.SchDoc, NODEMCU_DEVKIT_V1.0.PcbDoc]
2015-02-07 Optimization the micro USB footprint.
    [NODEMCU_DEVKIT_V1.0.PcbDoc]
2015-02-07 Update micro USB via and solder mask.
    [NODEMCU_DEVKIT_V1.0.PcbDoc]
2015-02-07 Layout micro USB.
    [04_POWER.SchDoc, NODEMCU_DEVKIT_V1.0.PcbDoc]
2015-02-07 Layout and route completed.
    [NODEMCU_DEVKIT_V1.0.PcbDoc]
2015-02-08 Finished VIA placement.
    [NODEMCU_DEVKIT_V1.0.PcbDoc, NODEMCU_DEVKIT_V1.0.PrjPCB]
2015-02-08 NodeMCU AMICA bottom overlay drawing.
    [01_SYSTEM.SchDoc, 05_IO_CONN.SchDoc, NODEMCU_DEVKIT_V1.0.PrjPCB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]
2015-02-09 Add Gerber files.
    [NODEMCU_DEVKIT_V1.0.PrjPCB, OpenHW.PcbDoc]
2015-02-09 Add Gerber File and pin offset file.
    [OpenHW.PcbDoc]
2015-04-04 Remove amica logo.
    [01_SYSTEM.SchDoc, NODEMCU_DEVKIT_V1.0.PrjPCB]
2015-04-04 Update PCB and rules.
    [NODEMCU_DEVKIT_V1.0.PcbDoc, NODEMCU_DEVKIT_V1.0.PrjPCB]
2015-04-04 Add Gerber and PDF.
    [NODEMCU_DEVKIT_V1.0.PrjPCB]
2015-05-14 Update documents and schdoc.
    [01_SYSTEM.SchDoc, 02_ESP12_CORE.SchDoc, 03_USB_TO_UART.SchDoc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]
2015-05-14 Update pin map document.
2015-05-14 Rename Gerber files. Added NODEMCU_DEVKIT_V1.0_GERBER_V4.rar
2015-05-15 Update README.md
    Add ==How to flash== and ==Pin map==
2017-03-13 Altium Library with footprint and schematic
2017-03-13 Altium library, schematic and multiple footprints
